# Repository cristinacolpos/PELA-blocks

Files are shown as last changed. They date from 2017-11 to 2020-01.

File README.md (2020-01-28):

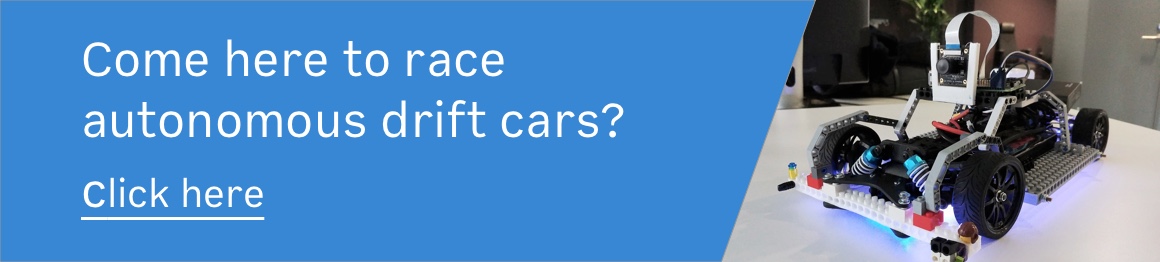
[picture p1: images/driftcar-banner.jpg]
PELA Drift Car (https://driftcar.pelablocks.org)


The fastest way to get support on designing and 3D printing your custom part is on [Discord PELA Blocks](https://discord.gg/Yy2srz)

# PELA Blocks

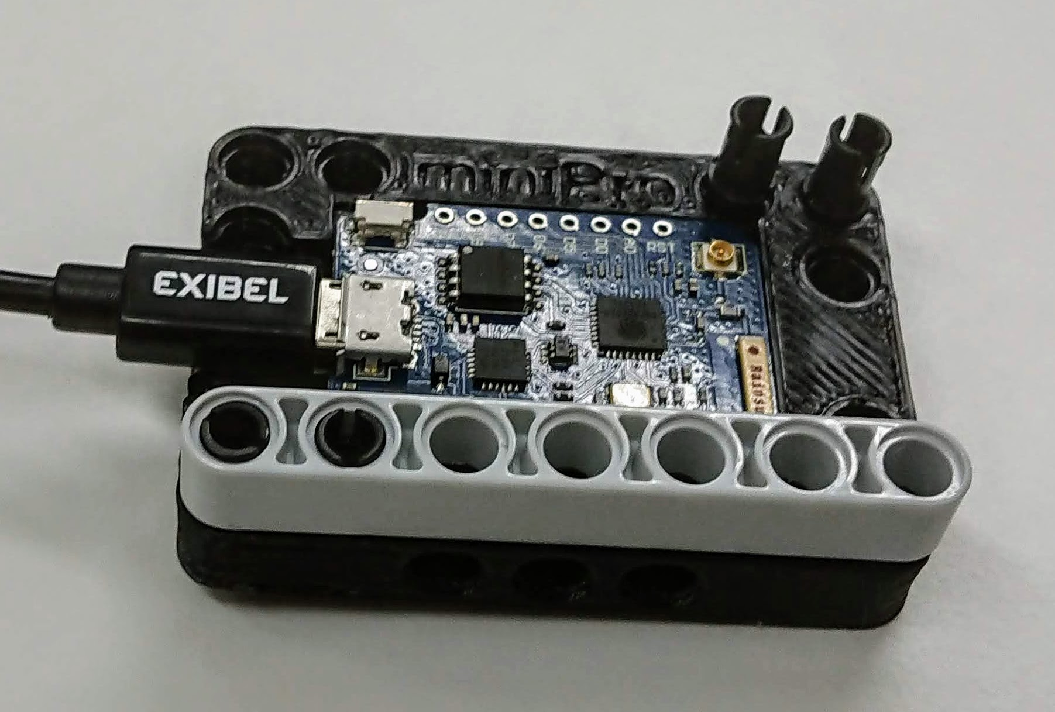
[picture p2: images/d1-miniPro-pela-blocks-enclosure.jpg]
ESP8266 d1 miniPro PELA Blocks enclosure


We measured the length, width and thickness of this board. Moving sliders in the customizer graphical interface of the  `PELA Technic Mount` created this functional prototype enclosure with nicely calibrated snap fit connectors. Now we can rapidly iterate our models in the field. 5 minutes plus 30 minutes for printing. This model is saved as a drop down preset of the `PELA Technic Mount` model.

Now you can design models without coding and snap them together!

## LEGO-compatible Parametric 3D Printed Blocks

PELA blocks are designed for easy 3D printing, strength, and rapid customization using free software. One time calibration gives perfect snap-together objects in exotic materials and geometries to help you explore your ideas and build with exotic materials and any motors and electronics you like. Example enclosures with many options for custom sensors, actuators, computers and IoT devices are included, or create your own.

These designs are not by the LEGO corporation. LEGO-compatible blocks are available from multiple manufacturers. Associated basic block patents expired long ago. Press-fit blocks existed before LEGO and we continue that tradition of adapt, evolve and improve as we provide these open source designs for 3D printing.

The name PELA comes from the Finnish "pelataan" meaning "let's play". This [blog post](https://medium.com/@futurice/rapid-hardware-prototyping-turbocharge-your-process-with-pela-blocks-58d0fcff63c5) on how we use these to build a self-driving 1:10 drift car is a good example of rapid prototyping "play".

## Download

**The STL files shown are not calibrated for your printer.** To get a good snap fit with your 3D printer and different material, you need to fine tune the size of knobs, sockets and technic holes. Some starting values are 

1. **[DOWNLOAD](https://github.com/LEGO-compatible-gadgets/PELA-blocks/archive/master.zip)** the latest designs, or `git clone git@github.com:LEGO-Prototypes/PELA-blocks.git --recurse-submodules`, then `git lfs install` in each git module
1. **[Calibrate](#calibrate)** the PELA Block models for your material and printer

See [Advanced Setup](ADVANCED-SETUP.md) for additional tricks.

See the [Slicer Recommendations](SLICER.md) for information about different printing materials we have tested.

## Calibrate

**TL;DR** *: To get a nice snap fit for your printer, slicer settings and material, print a calibration beam and test fit commercial bricks to the top knobs, bottom sockets and side technic holes. Update the best `top_tweak` and `bottom_tweak` into [`material.scad`](material.scad). Now open any model in OpenSCAD, press `F6` to generate the model then `F7` to export an STL.*

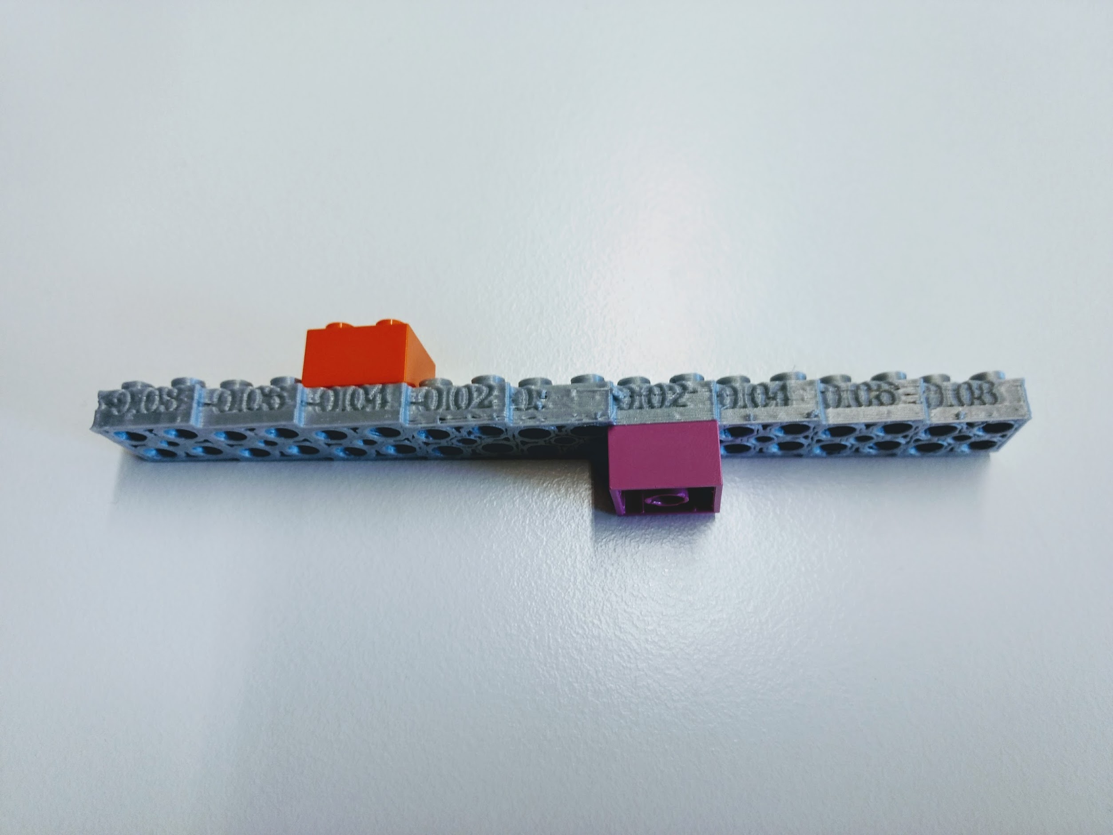
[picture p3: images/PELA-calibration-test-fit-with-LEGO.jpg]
PELA Example fit of a calibration block


There are several possible calibration beams. Most users will want the one linked below unless they are printing with flexible filament.

Test fit the top, bottom and sides to get something which is tight but not too tight. Then update your settings in  [`material.scad`](https://github.com/PELA-Prototypes/parametric-PELA/blob/master/material.scad) then one time calibration is complete.

## OpenSCAD Settings

The software needed is also free and open source, [OpenSCAD](https://www.openscad.org/). After install, `Edit | Preferences | Features | Customizer | Enable`. Also for large models and a fast machine, `Edit | Preferences | Advanced | Turn off rendering at _1000000_` and disable `OpenGL 1.0` compatability. 

You can also configure slicing and printing directly from OpenSCAD. See their website for details.

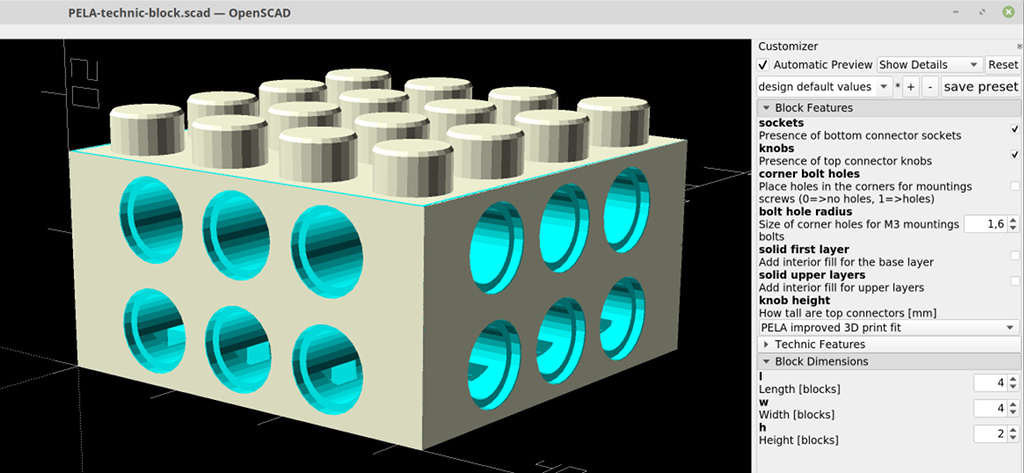
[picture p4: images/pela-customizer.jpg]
OpenSCAD Customizer with PELA Technic Block


___

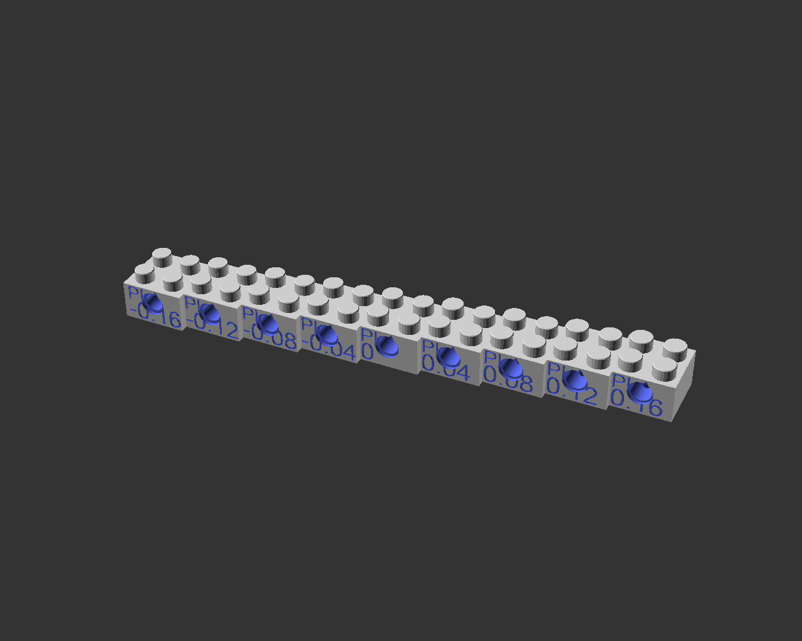
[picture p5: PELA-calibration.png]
PELA Calibration Beam, Normal Filament


[PELA Calibration Beam, Normal Filament](https://github.com/LEGO-compatible-gadgets/PELA-blocks/blob/master/PELA-calibration.stl) PELA Calibration Beam for standard filament (non-flexible).

### Calibration Instructions

Your printer, slicer settings, and plastic effect the precise fit. To correct for this, we adjust the models slightly for your printing process. Calibration is a one time process for each material. It is as simple as fitting two blocks together and editing a text file, [`material.scad`](material.scad) to indicate which test block fits best.

Before you print the calibration beam, be sure to set the `flexible_material` and `large_nozzle` settings in [`material.scad`](https://github.com/PELA-Prototypes/parametric-PELA/blob/master/material.scad).

After you print the clibration beam, you update three settings to get a tight fit: `top_tweak`, `bottom_tweak` and `axle_hole_tweak`. These can be read from the side of the calibration beam.

1. Print the Calibration Beam and test fit the top knobs and bottom sockets against commercial LEGO. Put the `top_tweak` (on the side, near the top) and `bottom_tweak` (on the side, near the bottom) values that you can read from the side of the beam into `material.scad`.
1. Use OpenSCAD to generate a new 2x2x1 `PELA Block` in OpenSCAD using these new settings, press `F6` to render, and `Export` as `.STL`.
1. Confirm a good fit with both commercial blocks and other PELA Blocks.
1. If you find you also need to adjust the technic connector hole size, print the Calibration Block Set. `axle_hole_tweak` numbers change along with `top_tweak` numbers.
1. Repeat this process as needed when you change material, nozzle size or and slicer settings which affect geometry.

## Advanced Calibration

An alternative set of individual calibration blocks are available, and if you have an unusual material there are other numbers you can tune such as various part thicknesses. See [Advanced Calibration](ADVANCED-CALIBRATION)

## PELA-compatible Part Designs

Edit `material.scad` and `style.scad` to adapt these models before printing them. **The example models below are not yet calibrated for your slicer and printer. Calibrate and then make the tuned model from the .scad file.**

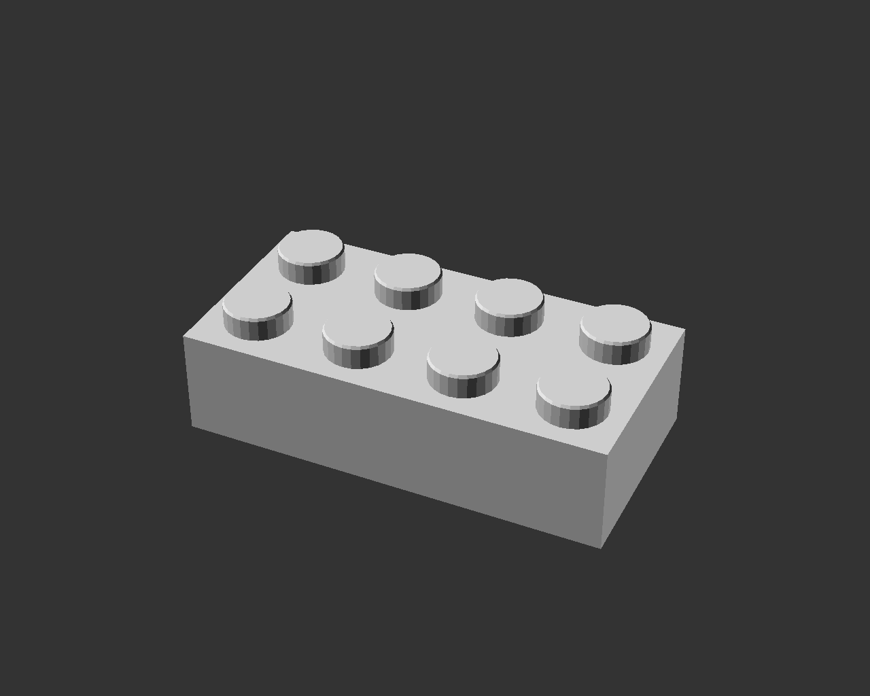
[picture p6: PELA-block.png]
PELA Block


[PELA Block](https://github.com/LEGO-compatible-gadgets/PELA-blocks/blob/master/PELA-block.stl)

___

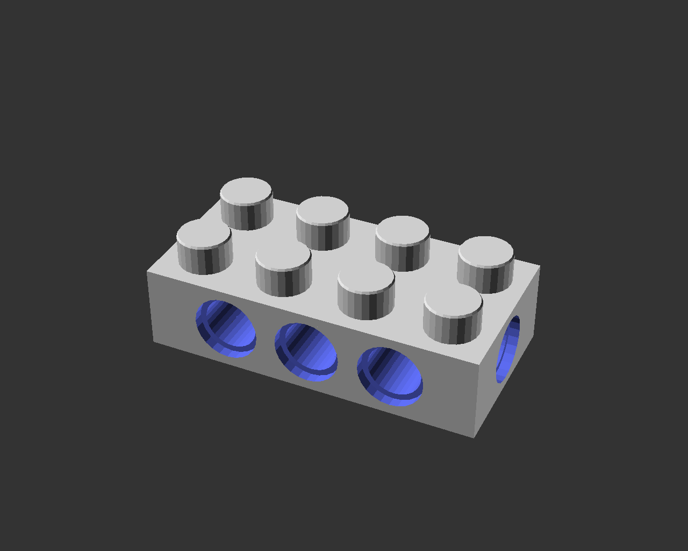
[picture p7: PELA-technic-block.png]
PELA Technic Block


[PELA Technic Block](https://github.com/LEGO-compatible-gadgets/PELA-blocks/blob/master/PELA-technic-block.stl) A blending of traditional and technic features which extends the basic block. All other models are extensions and variants of this.

___

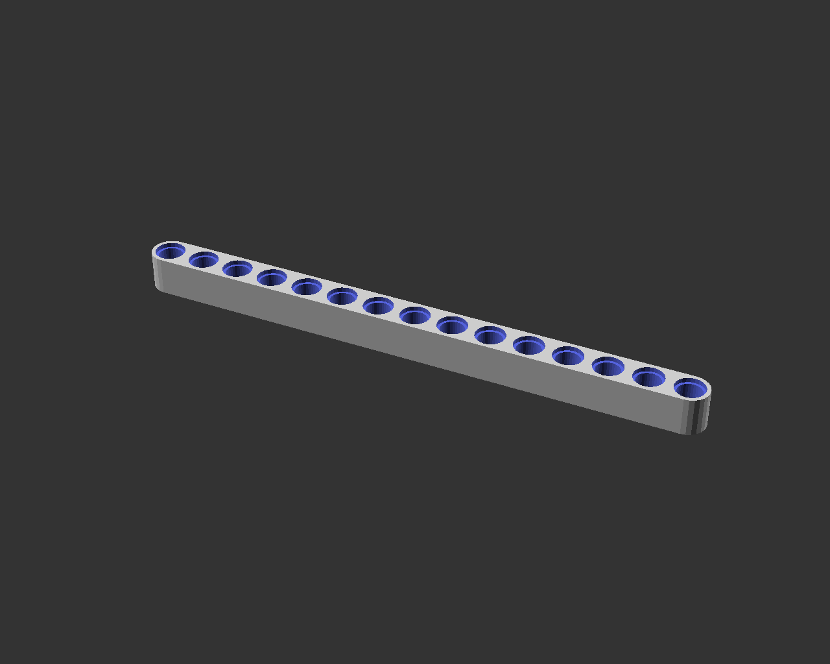
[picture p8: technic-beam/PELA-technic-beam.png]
PELA Technic Beam


[PELA Technic Beam](https://github.com/LEGO-compatible-gadgets/PELA-blocks/blob/master/technic-beam/PELA-technic-beam.stl) A minimalist technic beam.

___

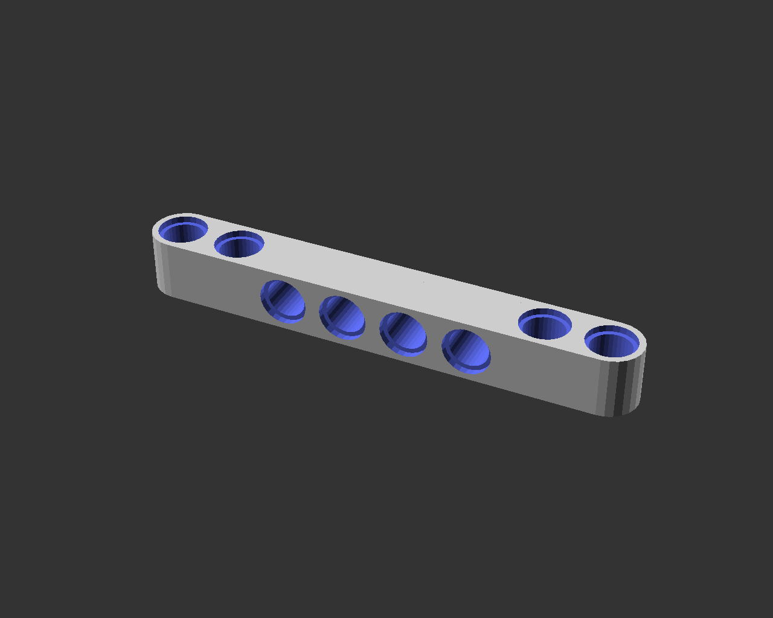
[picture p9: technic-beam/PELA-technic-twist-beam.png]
PELA Technic Twist Beam


[PELA Technic Twist Beam](https://github.com/LEGO-compatible-gadgets/PELA-blocks/blob/master/technic-beam/PELA-technic-twist-beam.stl) A technic beam with a center section of holes rotated 90 degrees.

___

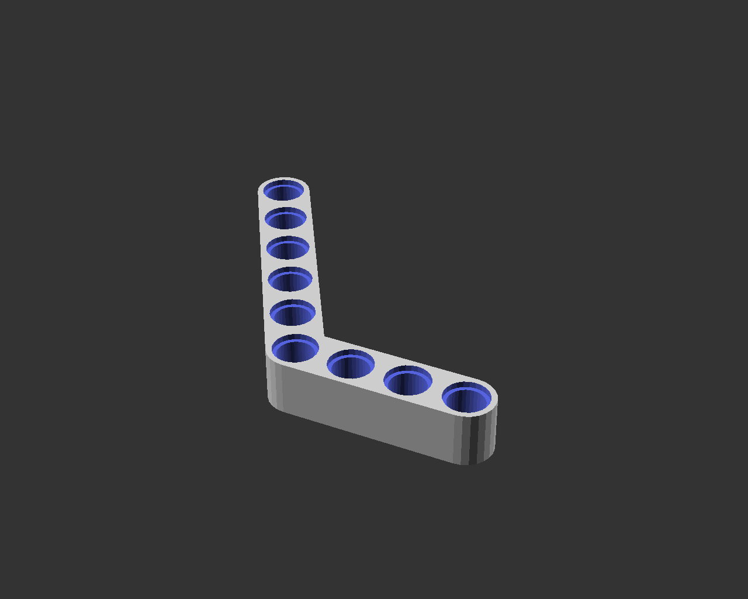
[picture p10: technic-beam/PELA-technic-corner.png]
PELA Technic Corner


[PELA Technic Corner](https://github.com/LEGO-compatible-gadgets/PELA-blocks/blob/master/technic-beam/PELA-technic-corner.stl) Two beams joined at an angle co-axial to the technic holes.

___

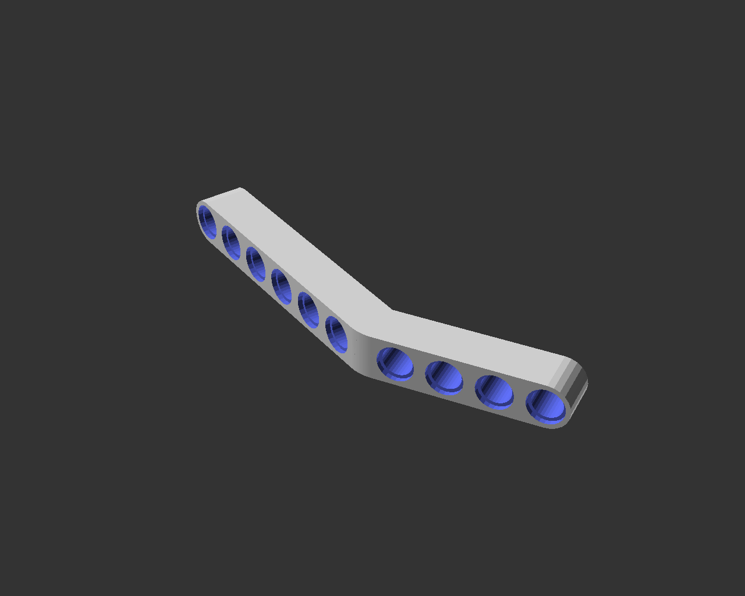
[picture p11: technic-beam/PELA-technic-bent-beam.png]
PELA Technic Bent Beam


[PELA Technic Bent Beam](https://github.com/LEGO-compatible-gadgets/PELA-blocks/blob/master/technic-beam/PELA-technic-bent-beam.stl) Two beams joined at an angle normal to the technic holes.

___

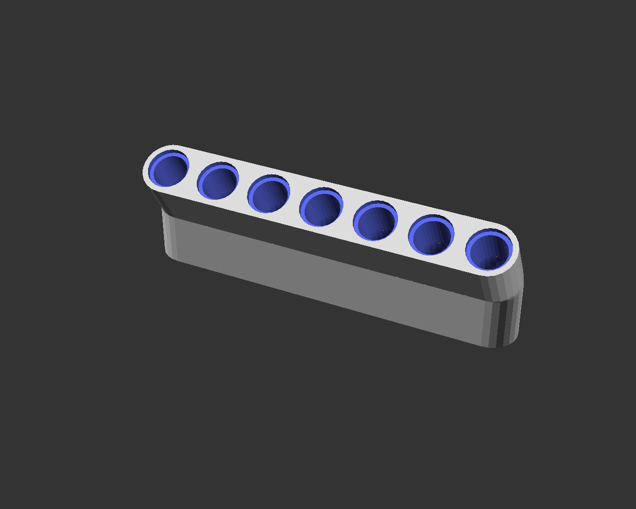
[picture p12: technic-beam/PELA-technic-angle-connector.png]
PELA Technic Angle Connector


[PELA Technic Angle Connector](https://github.com/LEGO-compatible-gadgets/PELA-blocks/blob/master/technic-beam/PELA-technic-angle-connector.stl) Two beams joined lengthwise at an angle.

___

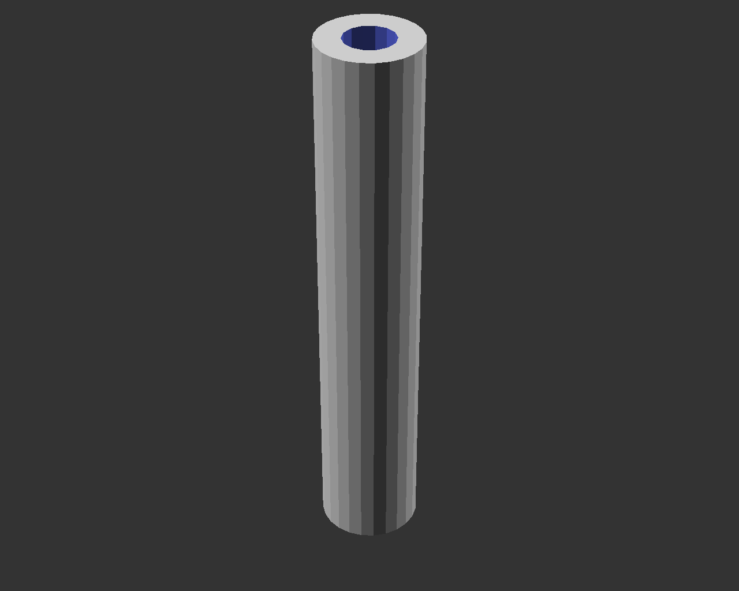
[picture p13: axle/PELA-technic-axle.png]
PELA Technic Axle


[PELA Technic Axle](https://github.com/LEGO-compatible-gadgets/PELA-blocks/blob/master/axle/PELA-technic-axle.stl) Rigid and flexible material shafts of adjustable length for attaching to other 3D printed designs such as wheels which you want to rotate freely.

___

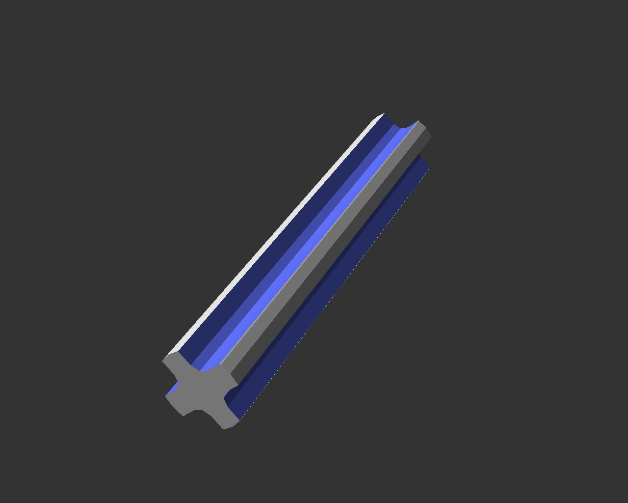
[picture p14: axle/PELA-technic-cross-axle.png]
PELA Technic Cross Axle


[PELA Technic Cross Axle](https://github.com/LEGO-compatible-gadgets/PELA-blocks/blob/master/axle/PELA-technic-cross-axle.stl) Rigid and flexible material torque drive shafts for adjustable length for attaching to other 3D printed designs.

___

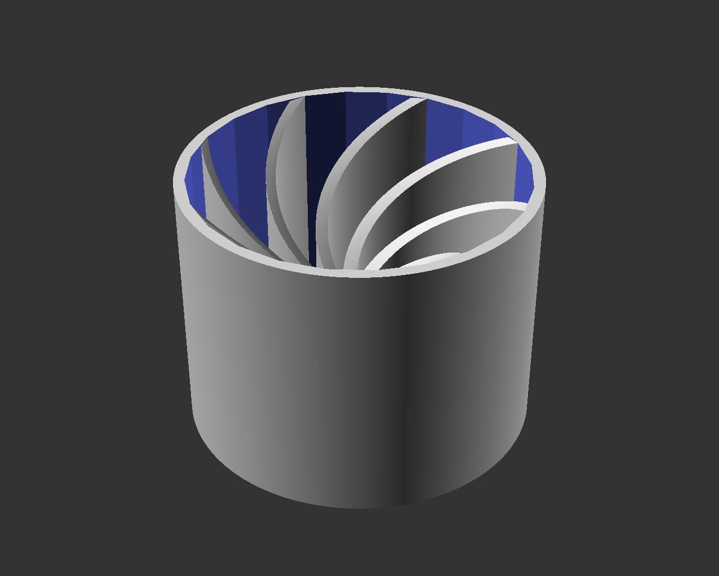
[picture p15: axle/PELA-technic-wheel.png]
PELA Technic Wheel


[PELA Technic Wheel](https://github.com/LEGO-compatible-gadgets/PELA-blocks/blob/master/axle/PELA-technic-wheel.stl) A spoked wheel that connects to a cross axle hub. Consider using flexible materials and tuning the wheel hardness as a simple shock absorber.

___

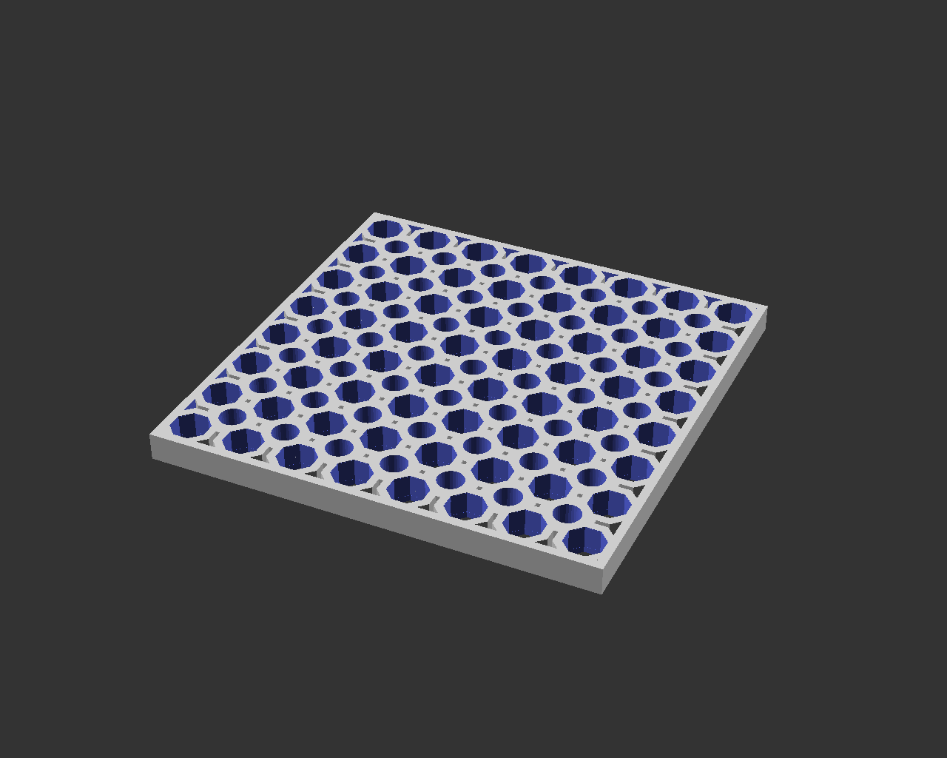
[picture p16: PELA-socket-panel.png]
PELA Socket Panel


[PELA Socket Panel](https://github.com/LEGO-compatible-gadgets/PELA-blocks/blob/master/PELA-socket-panel.stl) Insert knobs from both the top and bottom. Zoom in to see the subtle flexure ridges for enhanced "snap" fit.

___

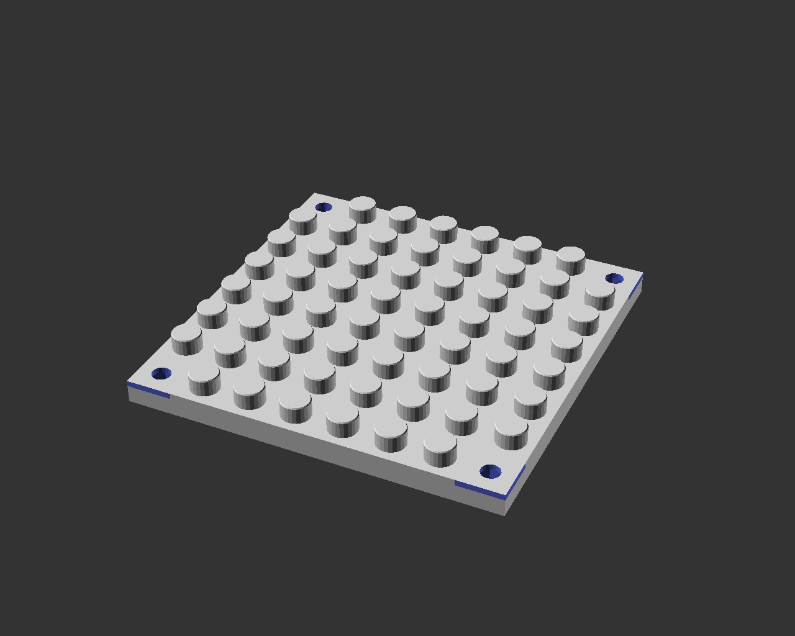
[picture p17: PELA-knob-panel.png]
PELA Knob Panel


[PELA Knob Panel](https://github.com/LEGO-compatible-gadgets/PELA-blocks/blob/master/PELA-knob-panel.stl) Optional corner holes for M3 bolts can be enabled

___

PELA Simplified Technic Peg

[PELA Simplified Technic Peg](https://github.com/LEGO-compatible-gadgets/PELA-blocks/blob/master/peg/PELA-simplified-technic-peg.stl) An easier-to-print version of a technic peg. This works best with a smaller nozzle and slightly flexible materials.

___

PELA Simplified Technic Peg for Flex Materials

[PELA Simplified Technic Peg for Flex Materials](https://github.com/LEGO-compatible-gadgets/PELA-blocks/blob/master/peg/PELA-simplified-technic-peg-flexmaterial.stl) An easier-to-print version of a technic peg for TPU95, TPU85/Ninjaflex and similar flexible materials.

___

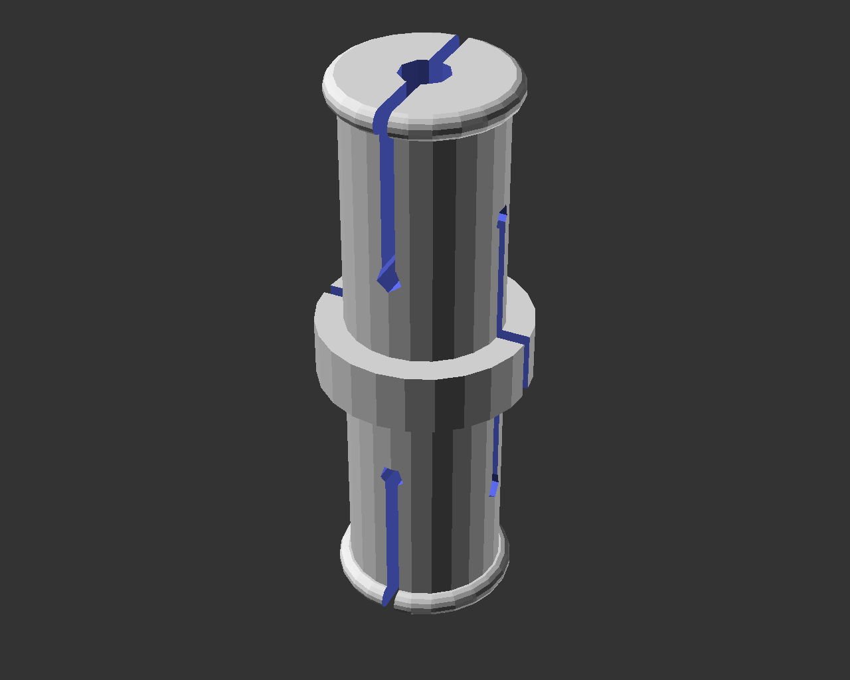
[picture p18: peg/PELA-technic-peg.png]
PELA Technic Peg


[PELA Technic Peg](https://github.com/LEGO-compatible-gadgets/PELA-blocks/blob/master/peg/PELA-technic-peg.stl) This is difficult to print with some material, but useful you run short and don't want to wait for mail order. It works best with slightly flexible materials.

___

PELA Technic Peg Array

[PELA Technic Peg Array](https://github.com/LEGO-compatible-gadgets/PELA-blocks/blob/master/peg/PELA-technic-peg-array.stl) A set of technic pegs.

___

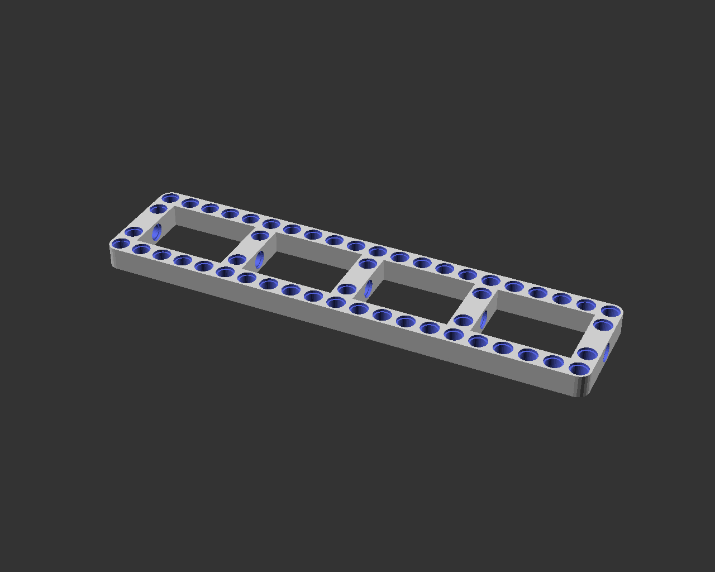
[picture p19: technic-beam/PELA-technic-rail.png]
PELA Technic Rail


[PELA Technic Rail](https://github.com/LEGO-compatible-gadgets/PELA-blocks/blob/master/technic-beam/PELA-technic-rail.stl) A variable length ladder-like mounting rail to bolt to a project board for clean, flexible layouts.

___

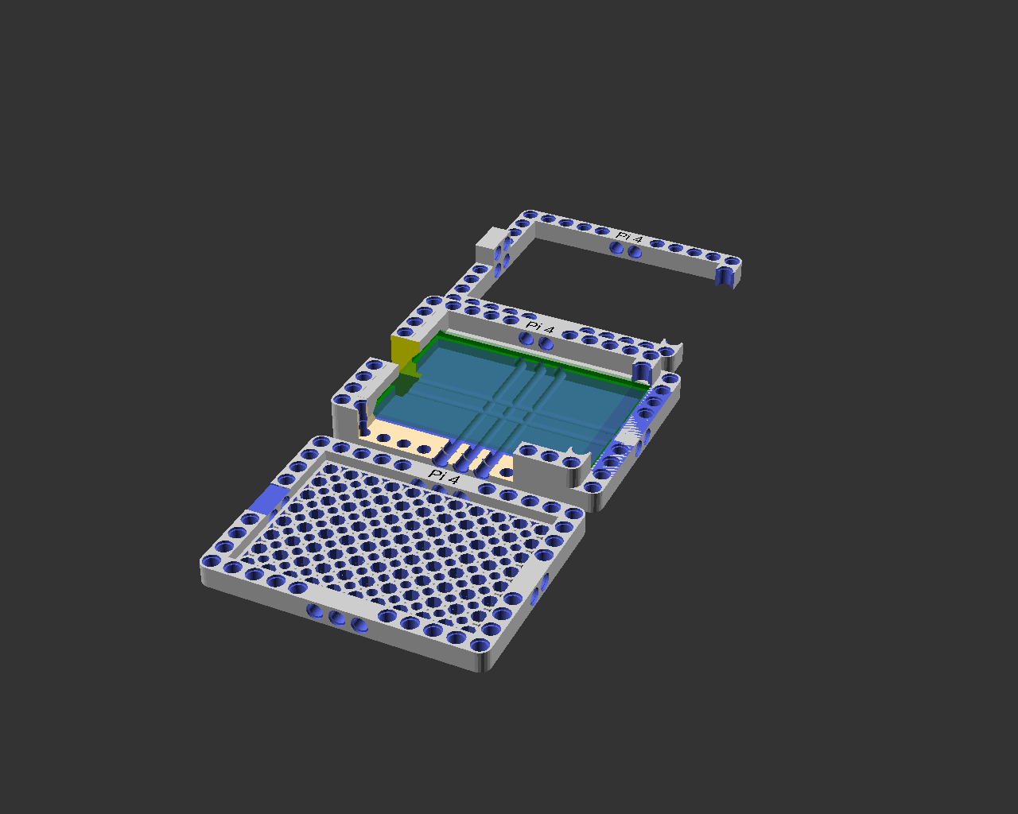
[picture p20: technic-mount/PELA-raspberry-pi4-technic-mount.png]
PELA Raspberry Pi 4 Technic Mount


[PELA Raspberry Pi 4 Technic Mount](https://github.com/LEGO-compatible-gadgets/PELA-blocks/blob/master/technic-mount/PELA-raspberry-pi4-technic-mount.stl) A Raspberry Pi 2/3B+/4 enclosure.

___

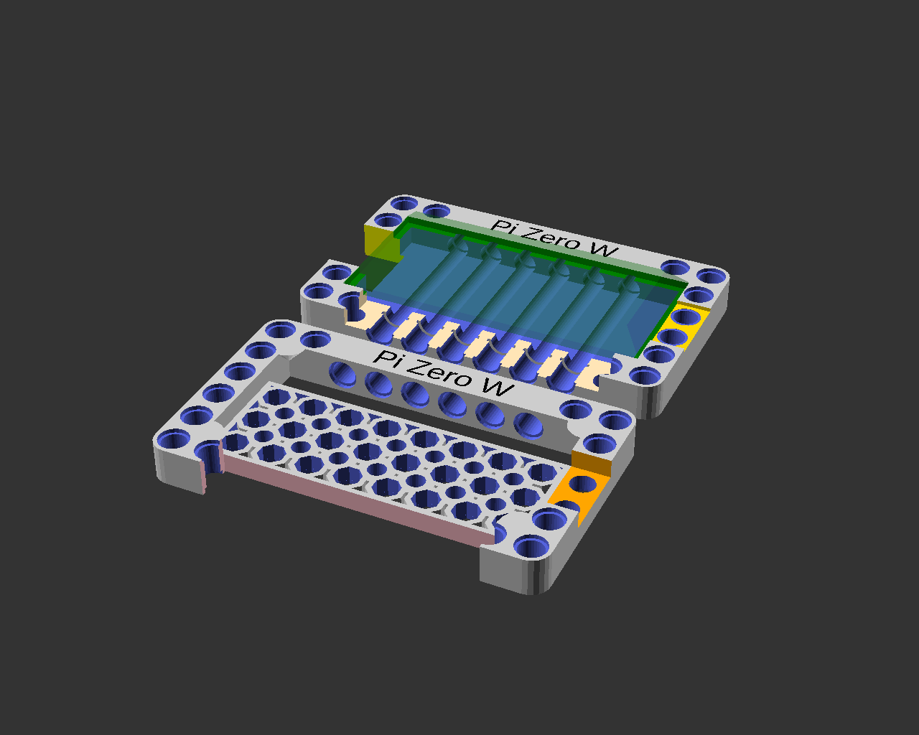
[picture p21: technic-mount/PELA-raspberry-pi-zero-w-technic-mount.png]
PELA Raspberry Pi Zero W Technic Mount


[PELA Raspberry Pi Zero W Technic Mount](https://github.com/LEGO-compatible-gadgets/PELA-blocks/blob/master/technic-mount/PELA-raspberry-pi-zero-w-technic-mount.stl) A Raspberry Pi Zero W holder.

___

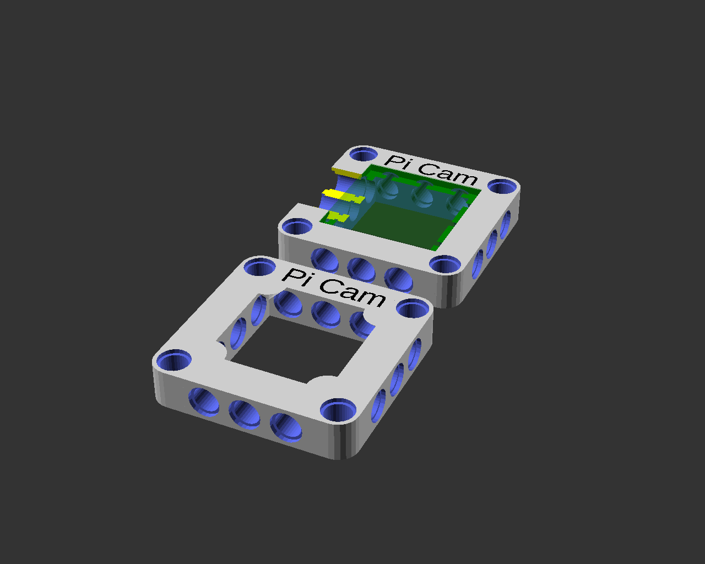
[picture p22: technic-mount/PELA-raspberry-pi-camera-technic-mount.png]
PELA Raspberry Pi Camera Technic Mount


[PELA Raspberry Pi Camera Technic Mount](https://github.com/LEGO-compatible-gadgets/PELA-blocks/blob/master/technic-mount/PELA-raspberry-pi-camera-technic-mount.stl) A Raspberry Pi camera holder.

___

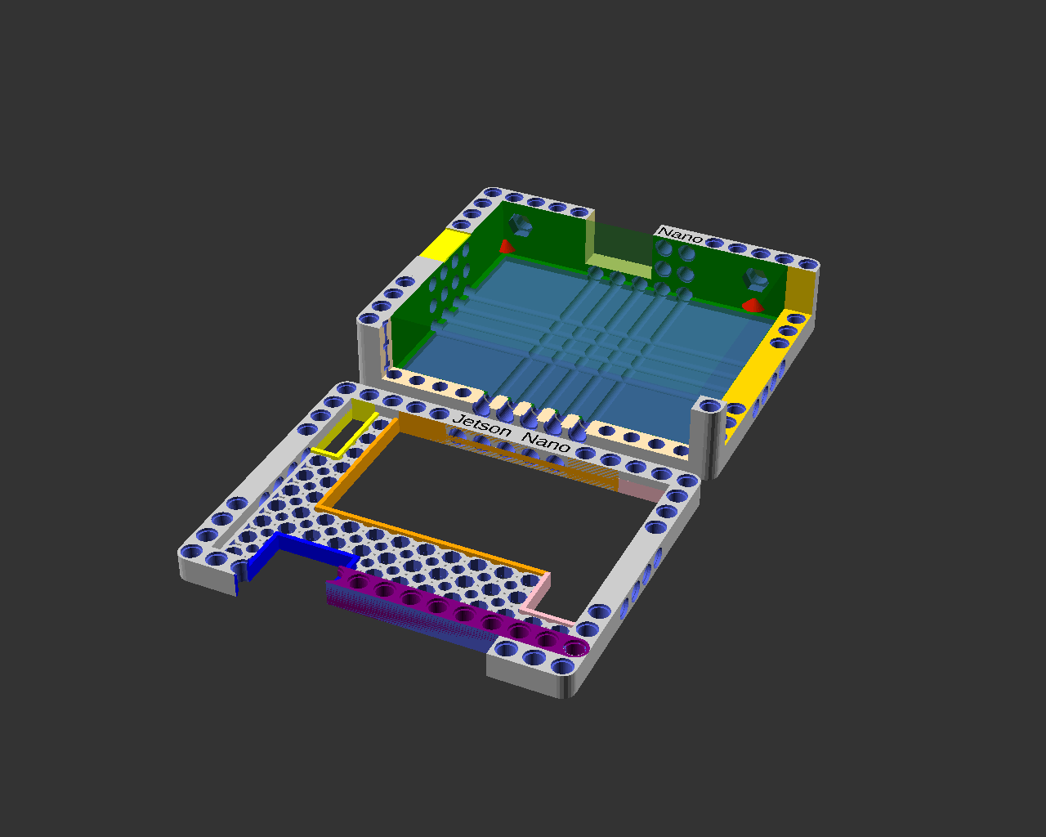
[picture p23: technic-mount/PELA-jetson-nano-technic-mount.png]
PELA Jetson Nano Technic Mount


[PELA Jetson Nano Technic Mount](https://github.com/LEGO-compatible-gadgets/PELA-blocks/blob/master/technic-mount/PELA-jetson-nano-technic-mount.stl) An NVIDEA Jetson Nano enclousure.

___

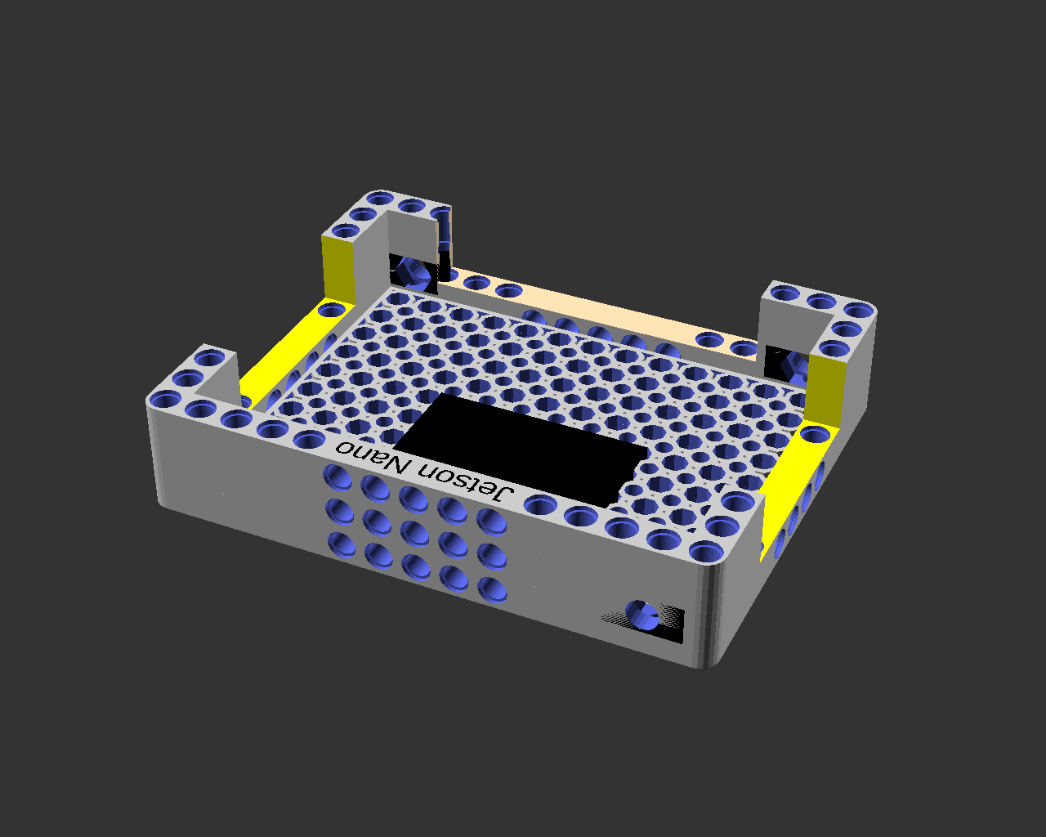
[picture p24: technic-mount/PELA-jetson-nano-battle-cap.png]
PELA Jetson Nano Battle Cap


[PELA Jetson Nano Battle Cap](https://github.com/LEGO-compatible-gadgets/PELA-blocks/blob/master/technic-mount/PELA-jetson-nano-battle-cap.stl) An NVIDEA Jetson Nano intrusion cover. This is useful to protect robots and self-driving cars from cooling fan impact damage which could break the PCB.

___

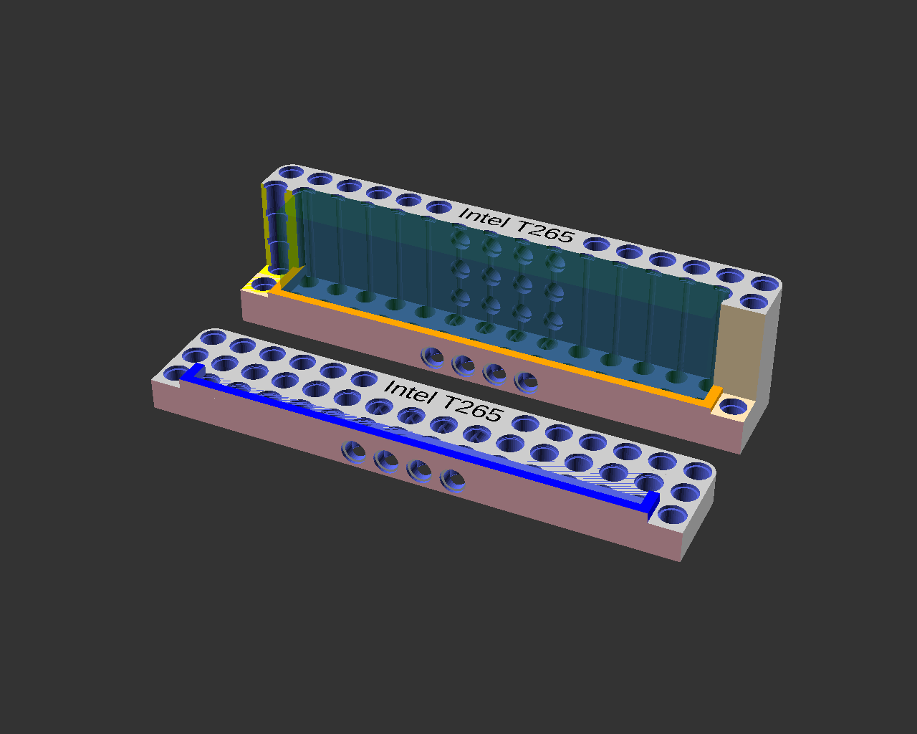
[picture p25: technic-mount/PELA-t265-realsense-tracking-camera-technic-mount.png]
PELA Intel T265 Realsense Tracking Camera Technic Mount


[PELA Intel T265 Realsense Tracking Camera Technic Mount](https://github.com/LEGO-compatible-gadgets/PELA-blocks/blob/master/technic-mount/PELA-t265-realsense-tracking-camera-technic-mount.stl) An enclosure for an [Intel T265](https://www.intelrealsense.com/tracking-camera-t265/) AI SLAM camera.

___

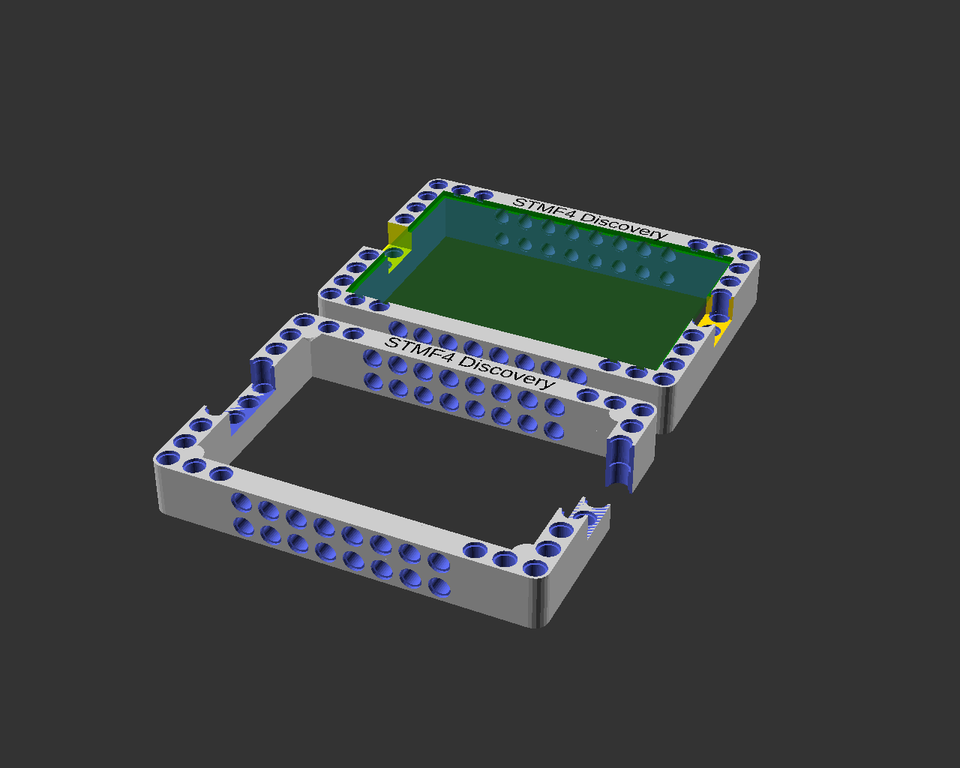
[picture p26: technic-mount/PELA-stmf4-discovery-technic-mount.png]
PELA STMF4 Discovery Technic Mount


[PELA STMF4 Discovery Technic Mount](https://github.com/LEGO-compatible-gadgets/PELA-blocks/blob/master/technic-mount/PELA-stmf4-discovery-technic-mount.stl) Enclosure for the [STMF4 Discovery](https://www.st.com/en/evaluation-tools/stm32f4discovery.html) board.

___

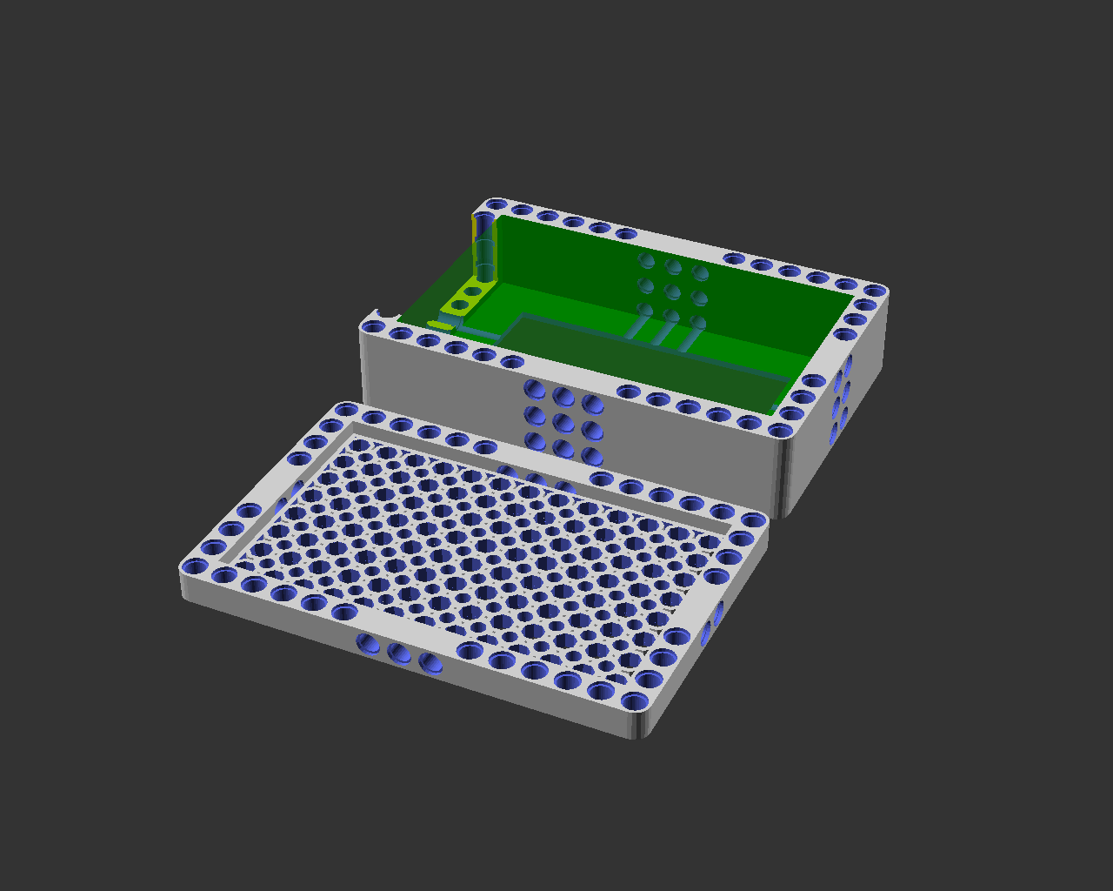
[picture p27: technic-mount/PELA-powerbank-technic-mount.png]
PELA Powerbank Technic Mount


[PELA Powerbank Technic Mount](https://github.com/LEGO-compatible-gadgets/PELA-blocks/blob/master/technic-mount/PELA-powerbank-technic-mount.stl) A container for a Clas Ohlson 38-3456 USB battery.

___

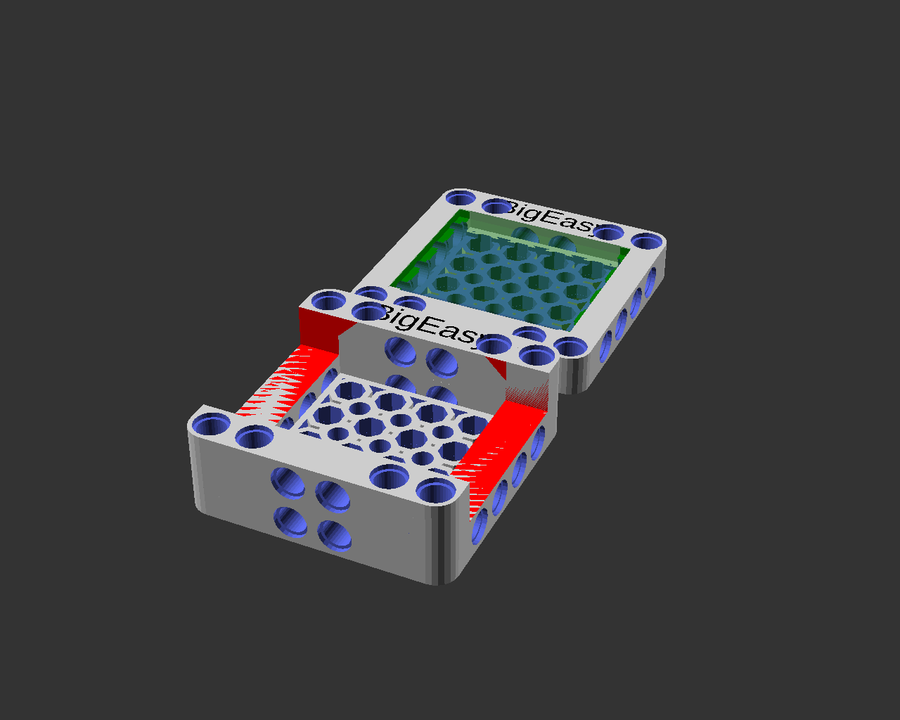
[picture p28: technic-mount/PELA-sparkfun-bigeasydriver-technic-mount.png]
PELA Sparkfun BigEasyDriver Technic Mount


[PELA Sparkfun BigEasyDriver Technic Mount](https://github.com/LEGO-compatible-gadgets/PELA-blocks/blob/master/technic-mount/PELA-sparkfun-bigeasydriver-technic-mount.stl) A pulsed infra-red motion sensor holder.

___

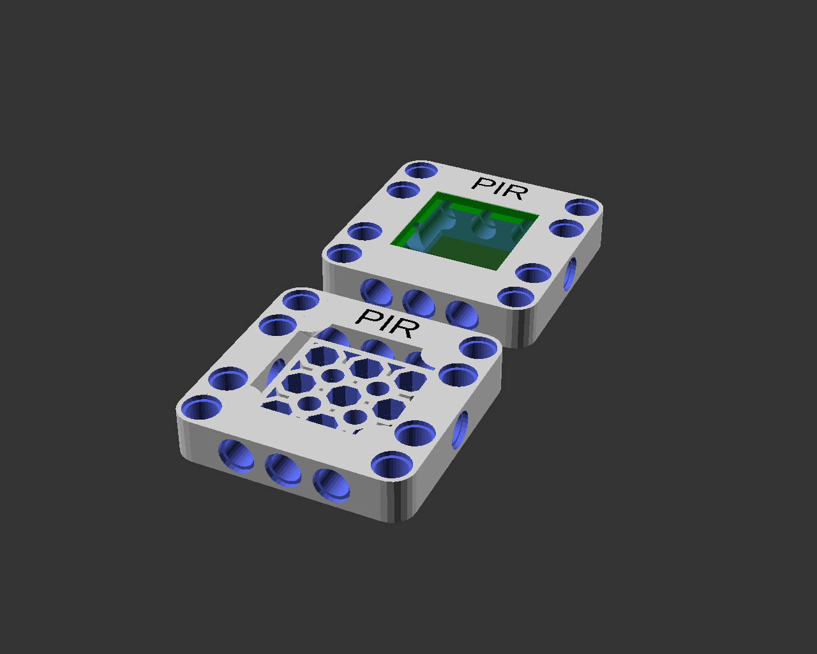
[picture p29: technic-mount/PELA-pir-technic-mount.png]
PELA Technic PIR Motion Sensor Mount


[PELA PIR Motion Sensor Technic Mount](https://github.com/LEGO-compatible-gadgets/PELA-blocks/blob/master/technic-mount/PELA-pir-technic-mount.stl) A pulsed infra-red motion sensor holder.

___

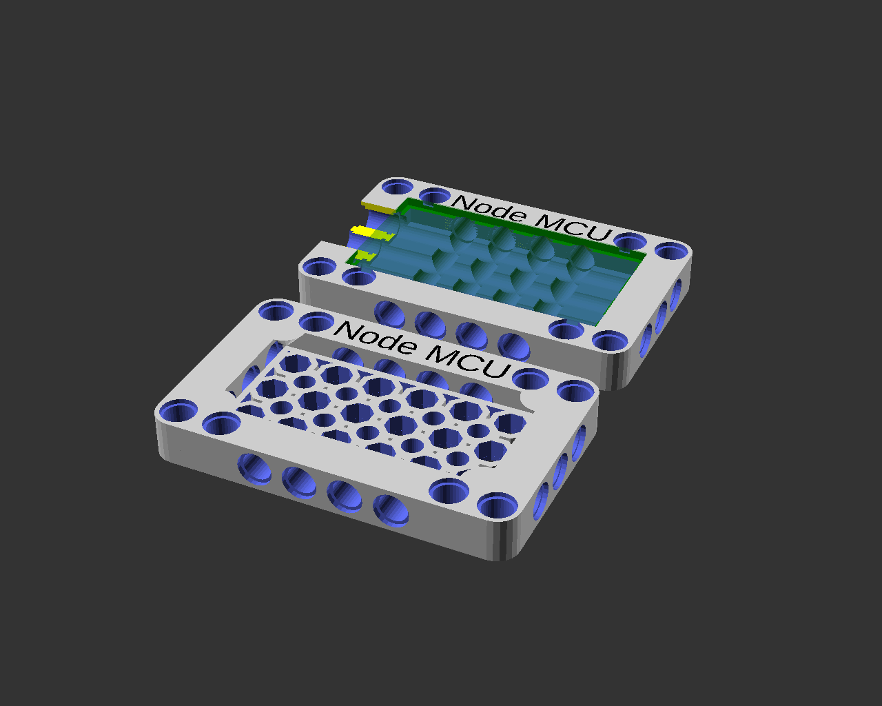
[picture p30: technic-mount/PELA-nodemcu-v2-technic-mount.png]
PELA Technic NodeMCU v2 Mount


[PELA Technic NodeMCU v2 Mount](https://github.com/LEGO-compatible-gadgets/PELA-blocks/blob/master/technic-mount/PELA-nodemcu-v2-technic-mount.stl) A technic mount for NodeMCU v2.

___

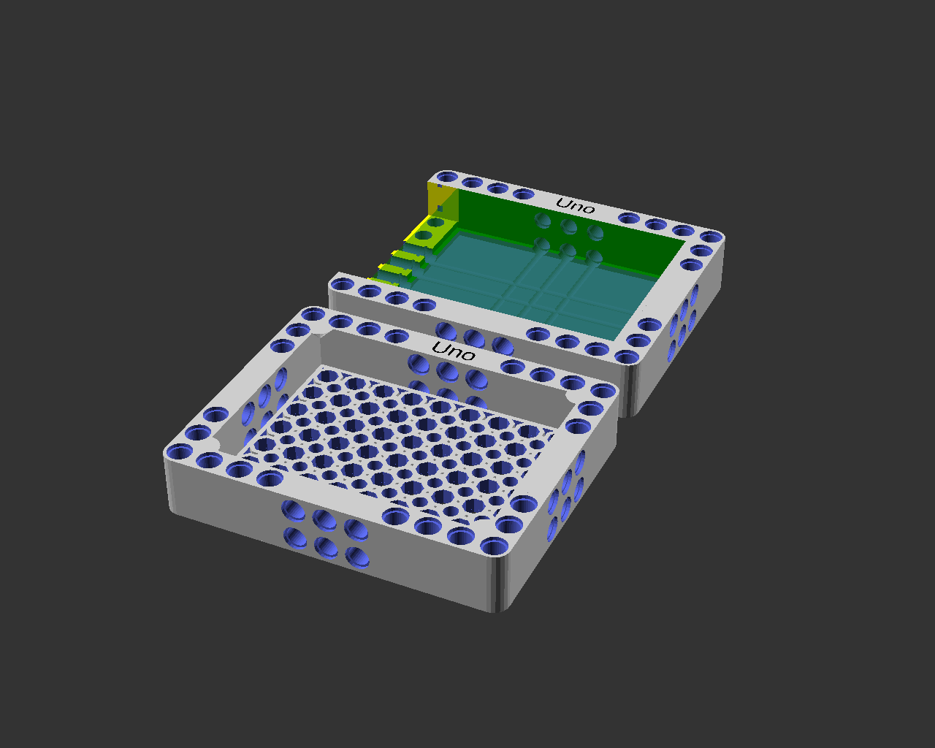
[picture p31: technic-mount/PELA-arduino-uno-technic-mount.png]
PELA Arduino Uno Technic Mount


[PELA Arduino Uno Technic Mount](https://github.com/LEGO-compatible-gadgets/PELA-blocks/blob/master/technic-mount/PELA-arduino-uno-technic-mount.stl) For holding an Arduino Uno microcontroller board within a PELA block

___

PELA Technic Seeed Respeaker Core v2 Mount

[PELA Technic Seeed Respeaker Core v2 Mount](https://github.com/LEGO-compatible-gadgets/PELA-blocks/blob/master/technic-mount/PELA-respeaker-core-v2-mount.stl) A technic mount for the Respeaker Core v2 microphone array.

___

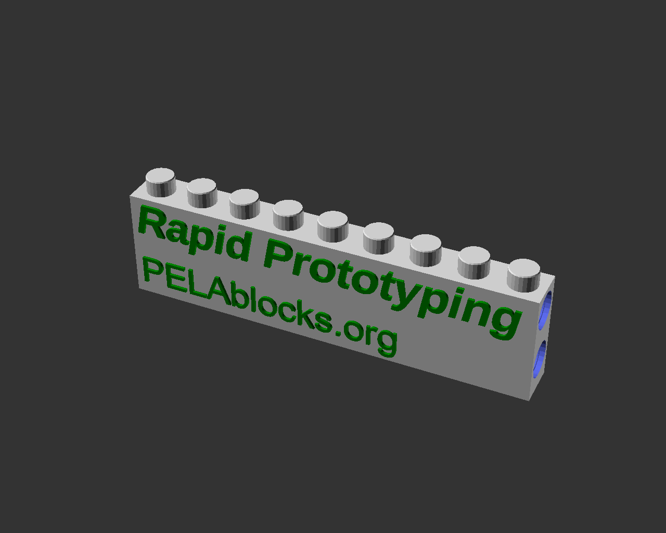
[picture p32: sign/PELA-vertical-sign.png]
PELA Vertical Sign


[PELA Vertical Sign](https://github.com/LEGO-compatible-gadgets/PELA-blocks/blob/master/sign/PELA-vertical-sign.stl) Change the text to label your designs. Options include front and back text with either etched for raised text.

___

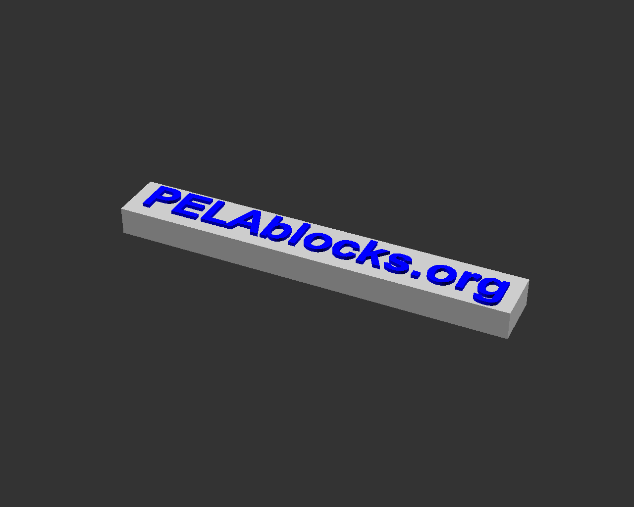
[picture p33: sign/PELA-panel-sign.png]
PELA Panel Sign


[PELA Panel Sign](https://github.com/LEGO-compatible-gadgets/PELA-blocks/blob/master/sign/PELA-panel-sign.stl) Change the text to label your design either etched for raised text.

___

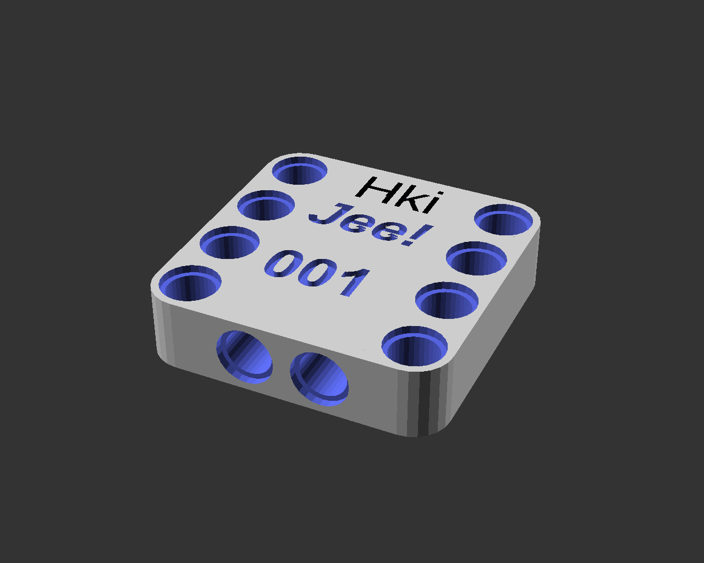
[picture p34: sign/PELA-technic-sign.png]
PELA Technic Sign


[PELA Technic Sign](https://github.com/LEGO-compatible-gadgets/PELA-blocks/blob/master/sign/PELA-technic-sign.stl) Change the text to label your design.

___

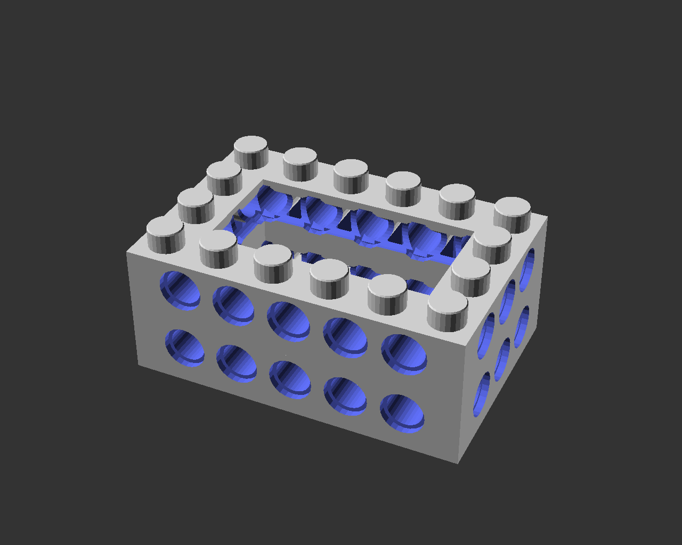
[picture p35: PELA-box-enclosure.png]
PELA Box Enclosure


[PELA Box Enclosure](https://github.com/LEGO-compatible-gadgets/PELA-blocks/blob/master/PELA-box-enclosure.stl) A generic enclosure for mounting boards inside protective side walls.

___

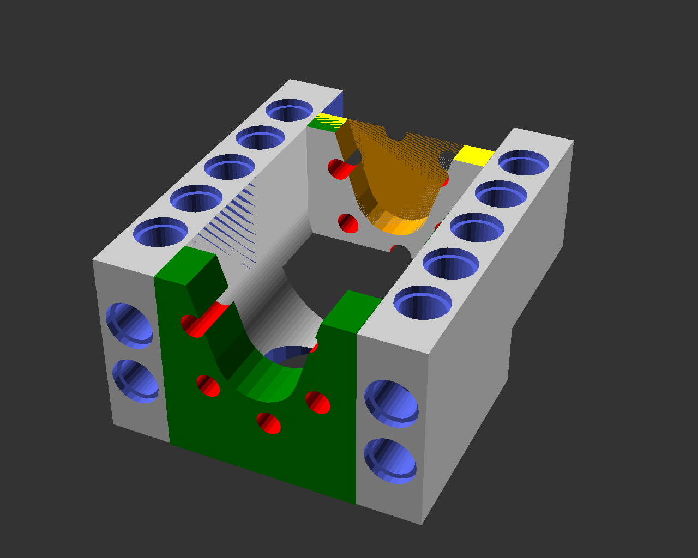
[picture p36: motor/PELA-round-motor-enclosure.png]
PELA Round Motor Enclosure


[PELA Round Motor Enclosure](https://github.com/LEGO-compatible-gadgets/PELA-blocks/blob/master/motor/PELA-round-motor-enclosure.stl) Add a round round motor holder for 1:10 electric cars

___

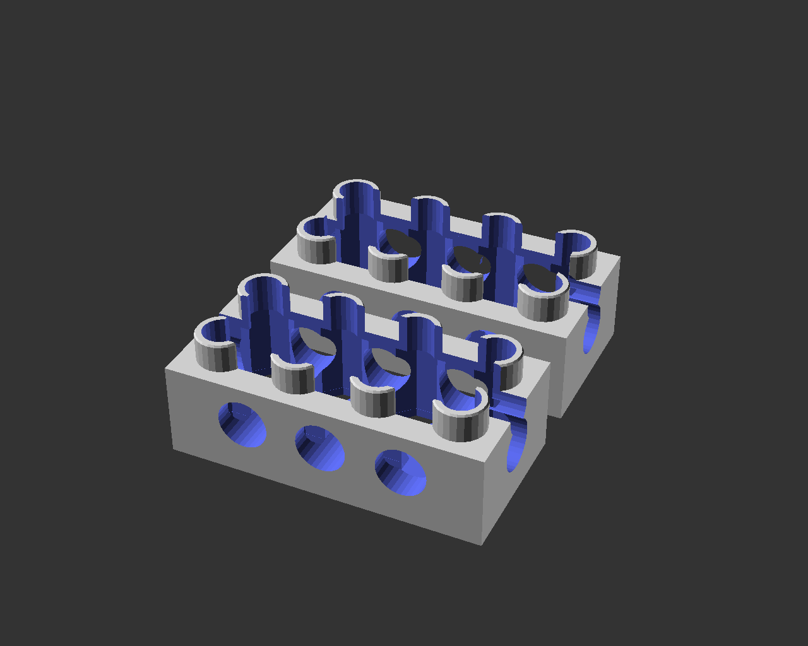
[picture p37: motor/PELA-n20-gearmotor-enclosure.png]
PELA N20 Gearmotor Enclosure


[PELA N20 Gearmotor Enclosure](https://github.com/LEGO-compatible-gadgets/PELA-blocks/blob/master/motor/PELA-n20-gearmotor-enclosure.stl) Add a commonly available small gear motor to your design. Adjust the model parameters to fit other motor sizes.

___

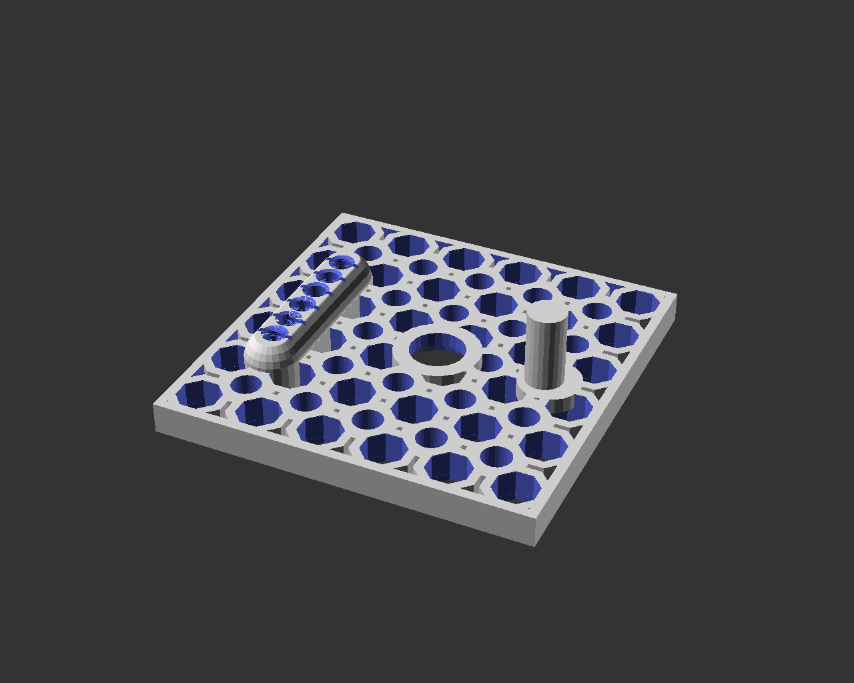
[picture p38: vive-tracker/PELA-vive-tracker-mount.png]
PELA HTC Vive Tracker Mount


[PELA HTC Vive Tracker Mount](https://github.com/LEGO-compatible-gadgets/PELA-blocks/blob/master/vive-tracker/PELA-vive-tracker-mount.stl) [HTC Vive Tracker](https://www.vive.com/) attachment to your designs becomes easy to remove.

___

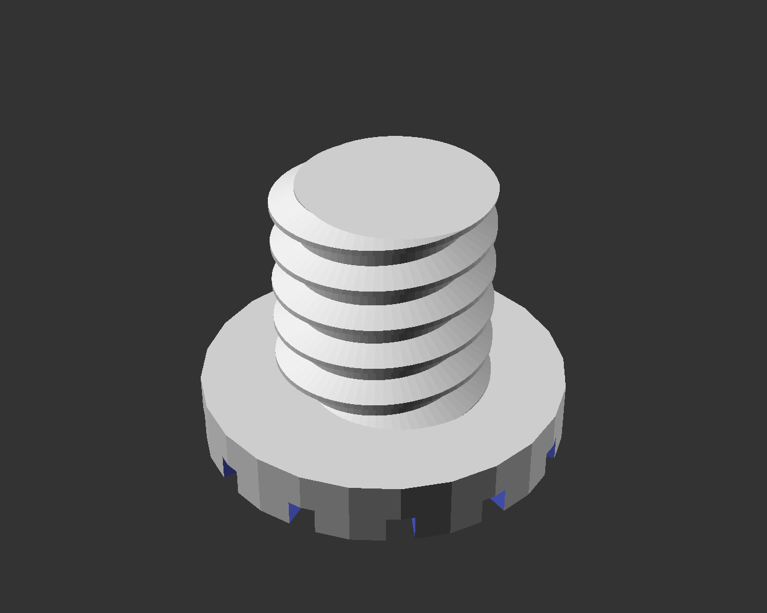
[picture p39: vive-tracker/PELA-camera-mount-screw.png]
PELA Camera Mount Screw


[PELA Camera Mount Screw](https://github.com/LEGO-compatible-gadgets/PELA-blocks/blob/master/vive-tracker/PELA-camera-mount-screw.stl) You can use this quarter inch standard camera mount screw for flush mounting the HTC Vive to the Vive Tracker Mount. The printed version works better than you might expect.

___

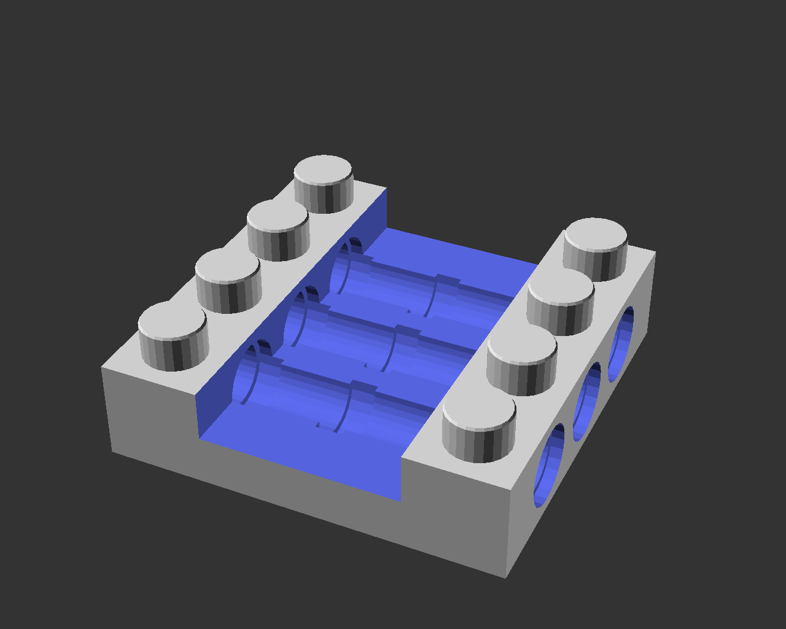
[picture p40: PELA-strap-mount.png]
PELA Strap Mount


[PELA Strap Mount](https://github.com/LEGO-compatible-gadgets/PELA-blocks/blob/master/PELA-strap-mount.stl) For attaching using strap or similar straps through the bottom slot. For example use this with velcro straps to mount Vive trackers on your shoes..

___

PELA PCA9685 16 Channel Servo Board Technic Mount

[PELA PCA9685 16 Channel Servo Board Technic Mount](https://github.com/LEGO-compatible-gadgets/PELA-blocks/blob/master/technic-mount/PELA-pca9685-servo-board-technic-mount.stl) For holding a servo board within a PELA block with connectors exposed at one end. We use these with 1:10 RC drift cars and Rasperry Pi for a [PELA drift car](https://driftcar.pelablocks.org/) in the [Markku Invitational](https://markku.ai/) contest based on [Donkeycar](https://www.donkeycar.com/).

## FFF Printing Tips
§
* Use a 0.4mm or smaller nozzle if possible to avoid decimation of some socket details
* If slicing with Simplify 3D with 0.5mm or larger nozzle, you may want to set Simplify 3D to `Advanced | External Thing Wall Type | Allow single extrusion walls`
* Be aware that slicers may in some cases not be able to correct OpenSCAD STL export errors. These errors should be visible in layer preview as for example extra excursions back to origin. If this happens, open and clean the STL files first with for example Microsoft 3D Builder, Meshmixer or MeshLab. MeshLab command line examples can be found in `build.ps1`.
* Best results are achieved with durable materials that are not too stiff (PET, co-polymers like NGEN, semi-flexible and "engineering" materials instead of PLA and  carbon filled).
* Best results are achieved with smaller nozzle diameters. Adjust slicer settings for precision over speed. Layer height is not particularly important on most models.
* Think carefully before using very slippery materials such as Nylon.
* "standard" and "fast" print setting layer lines are helpful for extra connector grip provided the resulting print geometry is sufficiently accurate.
* A print "brim" the appears inside the model may negatively affect the bottom connector fit
* Leaving the blocks on a heated bed may negatively affect the bottom connector fit

## Resin Printing Tips

* If more than 2 layer tall PELA with a relatively solid interior not allowing drainage below the knobs, check if you need to expand the airhole to allow resin to drain from the flexure chamber inside each knob
* For translucent materials, setting knob_slice_count to 0 may make the interior structure look more like a standard PELA at the cost of a slight reduction of knob sidewall flex

## License



These designs are by PELA project contributors, not by the LEGO corporation. They are compatible with LEGO and similar blocks available from multiple manufacturers and online projects. The associated patents have expired. These designs are not identical to LEGO; they have been specially modified for easy 3D printing and offered in the spirit of open source collaborative innovation.

If what you want is available as injection molded plastic, buy it for the higher quality and durability. These model are helpful when you want something customized, a special color, an unusual material, and for replacement parts when you just can't wait.

Futurice (https://futurice.com)

These open source designs are brought to you by [Futurice](https://futurice.com) and contributions from the community. Come work with the best.

## Projects Using PELA Blocks

PELA has been used to create a self-driving car: 3D Printed LEGO-compatible Parametric 1:10 Scale RC Drift Car Based On PELA Blocks (https://driftcar.pelablocks.org)

[![PELA Technic Rails]()](https://github.com/LEGO-compatible-gadgets/PELA-blocks/blob/master/technic-beam/PELA-technic-rail.stl) and enclosures are a great way to make bigger IOT projects without the duct tape: 
IOT Rail Mounting Solution Based On PELA Blocks

PELA is also used to create robot parts: 3D Printed LEGO-compatible Parametric Robot Hand (https://robothand.pelablocks.org)

The generated 3D models displayed here are hosted in a separate GitHub project to minimize the size of pulling changes in this repo: [PELA-blocks](https://github.com/LEGO-compatible-gadgets/PELA-blocks)

## Alternative 3D Block Designs

If you don't find what you need, consider adding it, contact us or check out the many other excellent design available.

[marian42's excellent online technic part generator](https://marian42.de/partdesigner/) can help you make custom connectors and fixture easily. 

[Yeggi search for LEGO](https://www.yeggi.com/q/lego/)

[Thingiverse Parametric LEGO Group](https://www.thingiverse.com/groups/parametric-lego) is an alternate source for these block designs. These designs don't work with the online customizer (speed and complexity, multiple files), so the best path is still to install the newest [OpenSCAD](https://www.openscad.org/) and **[download](https://github.com/LEGO-compatible-gadgets/PELA-blocks/archive/master.zip)** the models.

## Contact

New models, collaboration and pull requests are welcome. You have the tools- now create something cool and share with the world : https://github.com/LEGO-compatible-gadgets/PELA-blocks

paul.houghton@futurice.com ( **[Blog](https://medium.com/@paulhoughton)** - **[Twitter](https://twitter.com/mobile_rat)**)

If you like what you see, please tweet and let others know!

Twitter link (https://twitter.com/intent/tweet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)

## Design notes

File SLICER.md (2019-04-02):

# PELA Blocks
## Slicer Recommmendations

Our experience with different materials are recommended below. Unless otherwise noted, prints are on a Lulzbot Taz 6, 0.5mm extruder, using LulzBot Cura.

Most designs are adjusted to print upright with any layer height. There is very little infill with most designs so using 50% does not greatly affect print speed. Adjust settings to minimize "hop and hunt" during printing on the intricate inner geometry. Avoid "brim" and "support" options if possible as they require difficult post-processing. Most models are do not require supports, but some models offer a switch for minimal, pre-placed supports added to the model. Minimize bed heating if you find the bottom edge distorted by melting.

# Disable slicer print supports

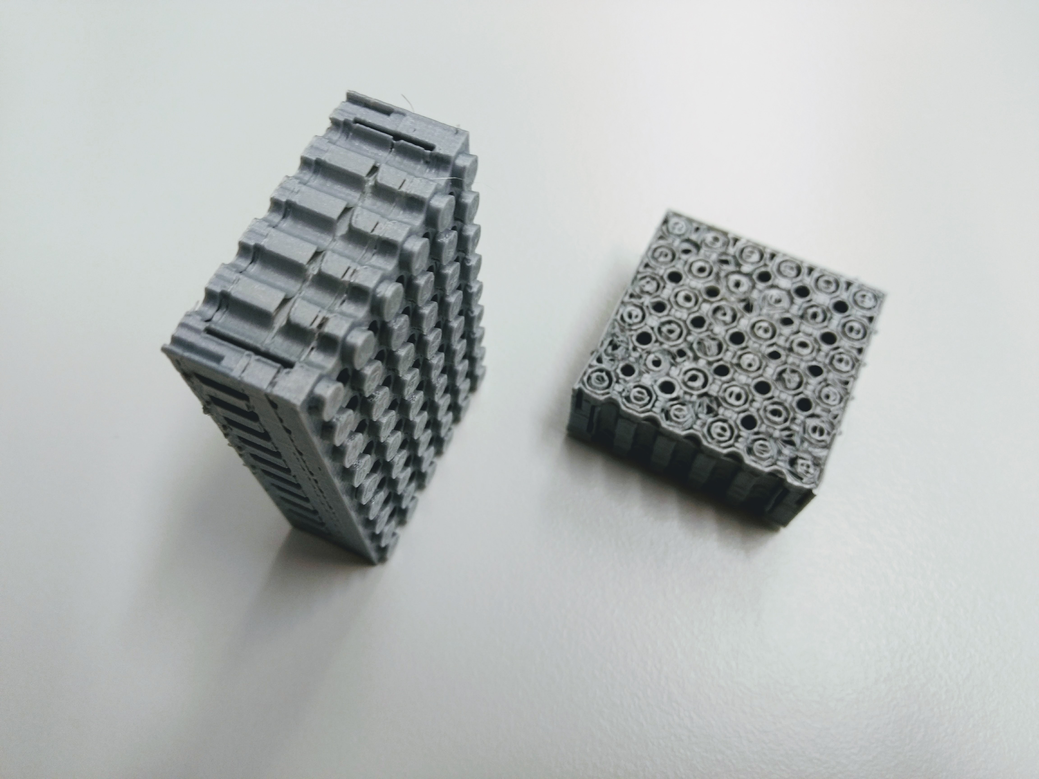
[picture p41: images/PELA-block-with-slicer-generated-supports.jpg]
PELA block with slicer-generated supports


In some models you can turn on `print_supports = true;` to enable pre-placed supports baked into the model. These may work better the slicer automatic supports to minimize post processing.

# PLA

Works surprisingly well if you use a premium PLA which has some flex to it. Some brands can be stiff and chip easily. That results in a more difficult part fit for knobs and sockets, but not so much problems with technic connector axle holes.

Avoid or minimize bed heating- it can "elephant foot" the lower socket connectors resulting in a poor fit.

# ABS

This is a good material if you are familiar with handling ABS shinkage. This is not much of an issue if your parts are not too large or too tall. LEGO is made from ABS because it has many nice properties if you know how to minimize lift and delamination due to thermal contraction in larger parts.

Not all brands of ABS are the same. Village Plastics ABS gives better results than some others.

# Innofil rPET

It works but is not ideal due to high stiffness and brittle failure. rPET is made from recycled plastic bottles. Like other transparent/translucent materials you can overextrude for more clarity. Just make sure you also print your calibration beam with the same overextrusion.

Other PETs which have more flex may be a good choice but have not been evaluated.

## Slicer Settings

`Layer Height: 0.25`     (for transparency- taller is fine and prints faster)

`Print Temp: 245C`

`Build Plate: 85C`

`Flow: 105%`

`Fan: 30%`

`Retraction: 8.5mm`

`Retraction Speed: 25mm/s`

`Speed: 80mm/s`

`Bottom Speed: 40mm/s`

`Support: None`   (see 'PEL-material.scad' where support can be added to some models)

`Adhesion: Skirt`

`Infill: 20%`   (minimal effect, most models this can be 50% without taking more time)

`Wall Line Count: 1`

`Fill Gaps Between Walls: Nowhere`

Optional Finish: Lightly sand the outer surface and spray with a clear polimer.

# Innofil Pro1

A nice engineering co-polimer with good gemetric stability and able to print fast and hold well to the print bed. It has good flexture- more than PET but still rigid.

## Slicer Settings

`Layer Height: 0.25`   (the manufacturer states lower layer heights are stronger and more aesthetic)

`Fan: 20%`   (lower speed is stronger layer adhesion, more speed gives cleaner geometry)

# Colorfabb NGEN

A strong, glossy material with a brittle failure mode. It works but is slightly tricky to get a good fit with classic knobs and sockets. As with PET/other co-copolymer filaments, unless you seek transparency then do not overextude. Consider adding more fan if layer adhesion is sufficent. Due to brittle failure knobs are particularly sensitive to breaking off from delamination in which case you may want to anneal parts in an oven or lower the fan for better layer adhesion.

## Slicer Settings

`Layer Height: 0.3`   (or smaller for aesthetics and when there is side text in the model)

`Print Temp: 255C`

`Initial Print Temp: 250C`

`Build Plate: 85C`

`Flow: 95%`

`Fan: 50%`

`Enable Coasting: true`

`Speed: 60mm/s`

`Wall Speed: 30mm/s`

`Support: None`

`Adhesion: Skirt`

`Infill: 20%`   (minimal effect, most models this can be 50% without taking more time)

`Wall Line Count: 1`

`Fill Gabs Between Walls: Nowhere`

# Colorfabb NGEN Flex

Works well on Taz6 Flexistruder with an 0.6mm nozzle. Basically the same settings as NGEN but without the drawbacks of being brittle which is very nice. Like NGEN it is a rather low friction glossy finish so calibration is still slightly sticky.

`Fan: 50%` or less for better inter-layer adhesion

# ColorFabb HT

Avoid. It is like NGEN but even more stiff, brittle failure and a slippery finish. It takes a long time to clean this sticky stuff from your printer.

# TPU85/NinjaTek NinjaFlex

Works well on a Taz6 Flexistruder with 0.6mm nozzle. Gluestick acts as a release agent that protects the PEI print surface from damage, or use tape or plain glass with gluestick.

## Slicer Settings

`Adhesion: Brim` Make sure the brim is only on the outside to avoid a difficult cleanup. Cura has an option for this. `Adhesion: Raft` also works but the bottom surface may be uneven. Minimize bed heating and use other adhesives during printing if needed to avoid "elephant foot" or "corner peel up" on the lower socket connectors.

`Infill: 20%`   (minimal effect, most models this can be 50% without taking more time)

`Wall Line Count: 1`

`Fill Gaps Between Walls: Nowhere`

`Keep Heating: No`

# Taulman Bridge Nylon

A very nice material for PELA blocks, but also very slippery. Use a bed of watery PVA white glue and take care not to permanently stick to a PEI or similar sheet. Use a lot of retraction to avoid string cleanup. Speed is your friend- print fast and retract fast and far, and enable "coast".

## Slicer Settings

`Layer Height: 0.3`

`Fill gaps between walls: Nowhere`       (Use Everywhere if the block is printed tilted or on the side)

`Keep Heating: No`      (Bed heater can be disabled after the print)

`Retraction Distance: 3mm`

`Retraction Speed: 20 mm/s`

`Print Speed: 100 mm/s`

`Number of Slow Layers: 1`

`Equalize Filament Flow: Yes`     (Move faster over thin walls)

`Print Cooling: 100%`

`Enable Coasting: Yes`    (Stop extrusion before the end of a segment to minimize oozing)

`Keep Heating: No`

# Biofila Silk

This is one of the most attractive filaments and biodegradable. It is between PLA and ABS is flexability and durability. Make sure you have good bed adhesion and adjust the settings for quick, long retraction to minimize stringing.

## Slicer Settings

`Layer Height: 0.25`

`Printing Temperature: 175C`

`Build Plate: 60C`

`Keep Heating: No`

`Infill: 50%`    (minimal impact on time)

`Fill gaps between walls: Nowhere`       (Use Everywhere if the block is printed tilted or on the side)

`Retraction Distance: 3mm`

`Retraction Speed: 20 mm/s`

`Print Speed: 70 mm/s`

`Number of Slow Layers: 1`

`Equalize Filament Flow: Yes`     (Move faster over thin walls)

`Print Cooling: 100%`

`Enable Coasting: Yes`    (Stop extrusion before the end of a segment to minimize oozing)

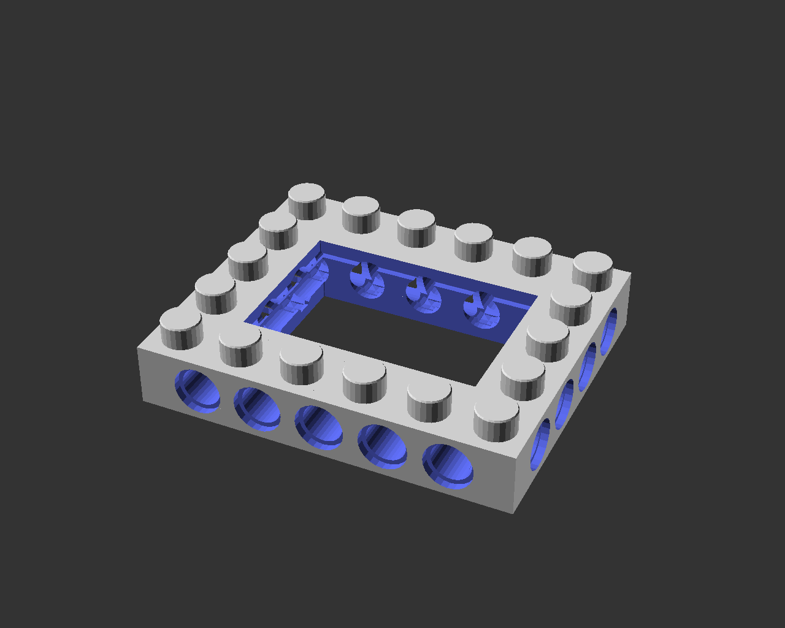
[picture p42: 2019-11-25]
PELA-knob-mount.png

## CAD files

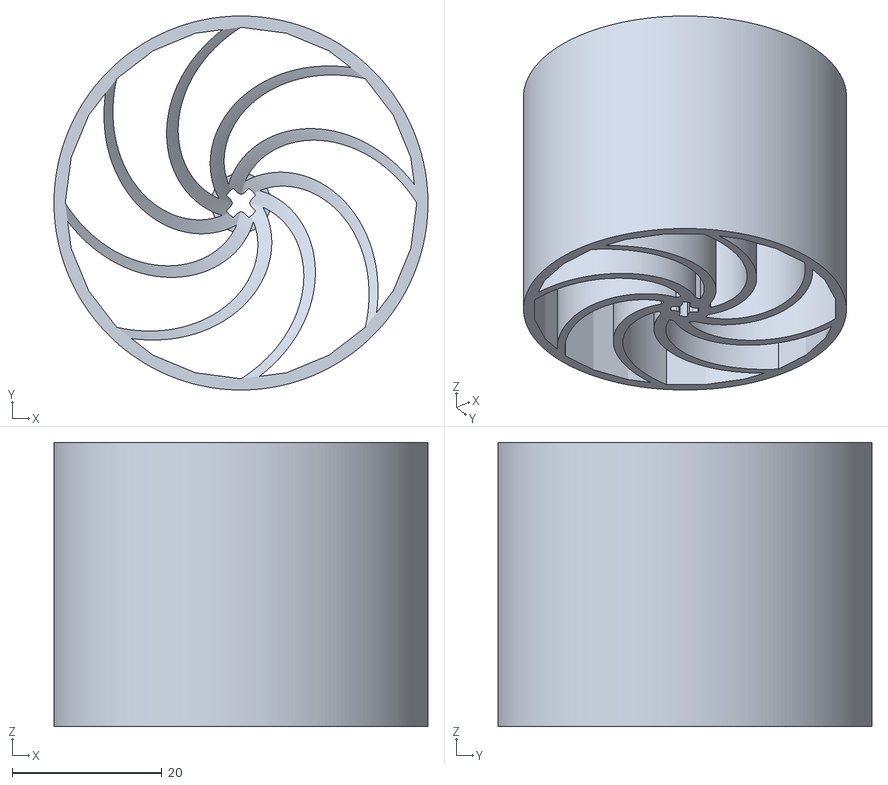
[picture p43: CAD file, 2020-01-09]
axle/PELA-technic-wheel.stl
50.0 x 50.0 x 38.0

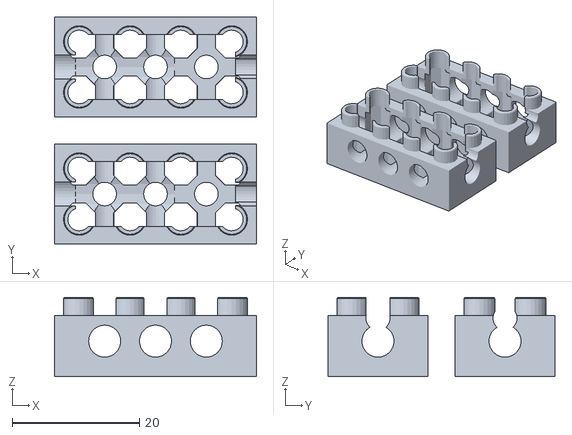
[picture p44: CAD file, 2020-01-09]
motor/PELA-n20-gearmotor-enclosure.stl
31.8 x 35.8 x 12.5

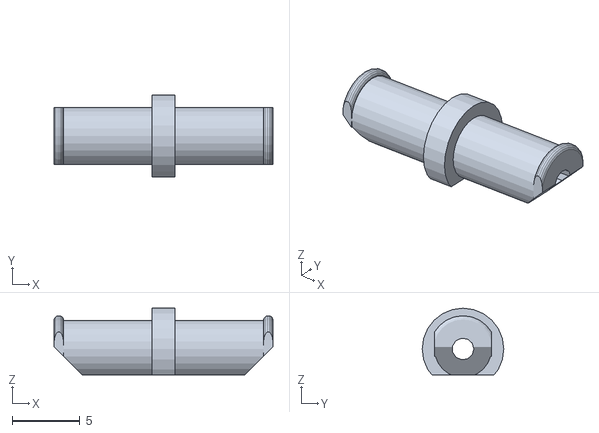
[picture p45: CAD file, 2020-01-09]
peg/PELA-simplified-technic-peg.stl
16.1 x 6.00 x 4.90

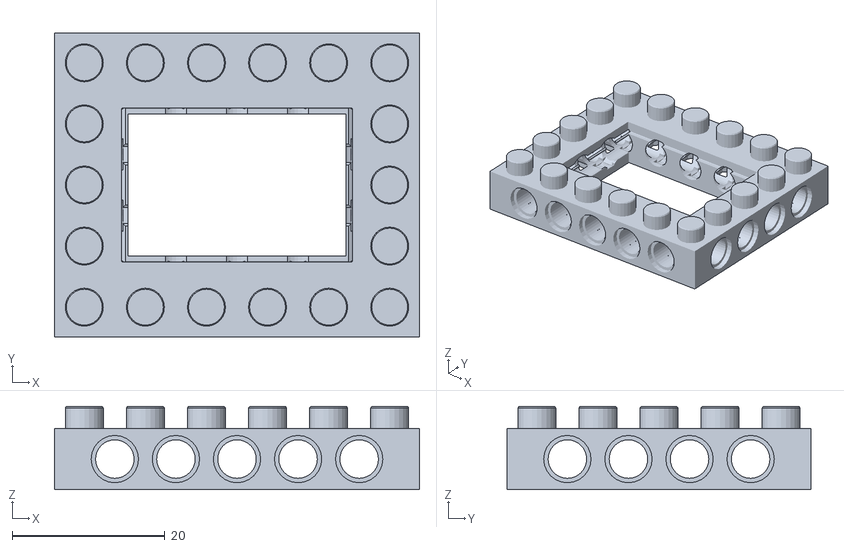
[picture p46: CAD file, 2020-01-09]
PELA-knob-mount.stl
47.8 x 39.8 x 10.9

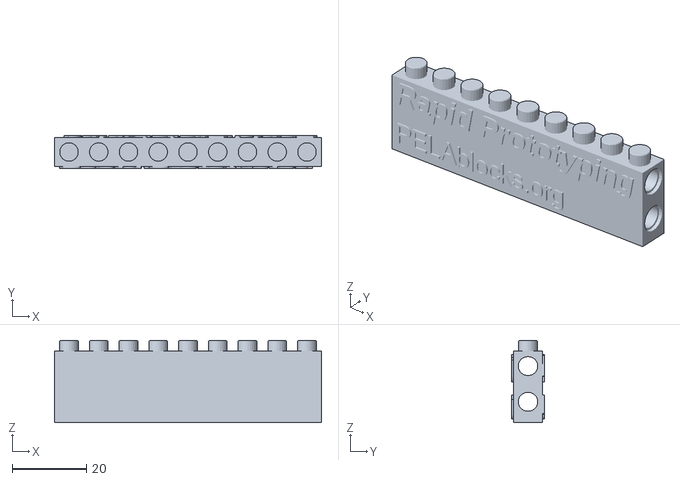
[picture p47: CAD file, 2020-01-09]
sign/PELA-vertical-sign.stl
71.8 x 8.80 x 22.1

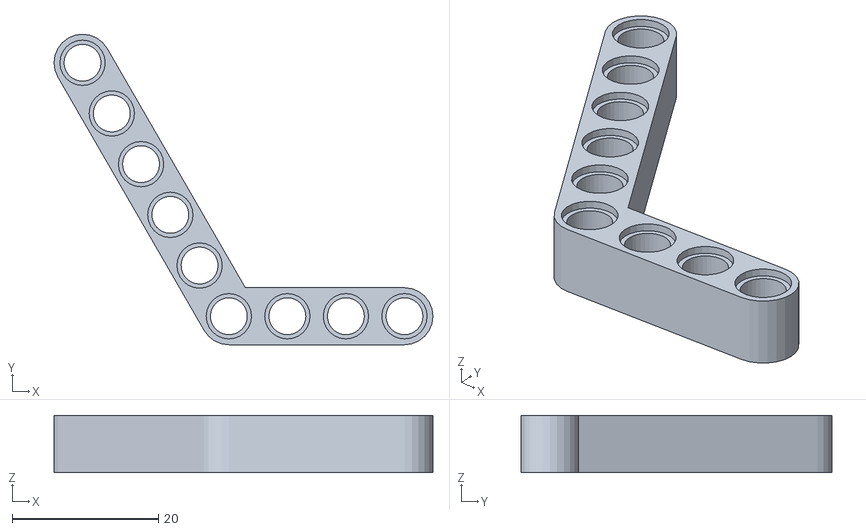
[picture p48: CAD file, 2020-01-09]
technic-beam/PELA-technic-corner.stl
51.8 x 42.4 x 7.80

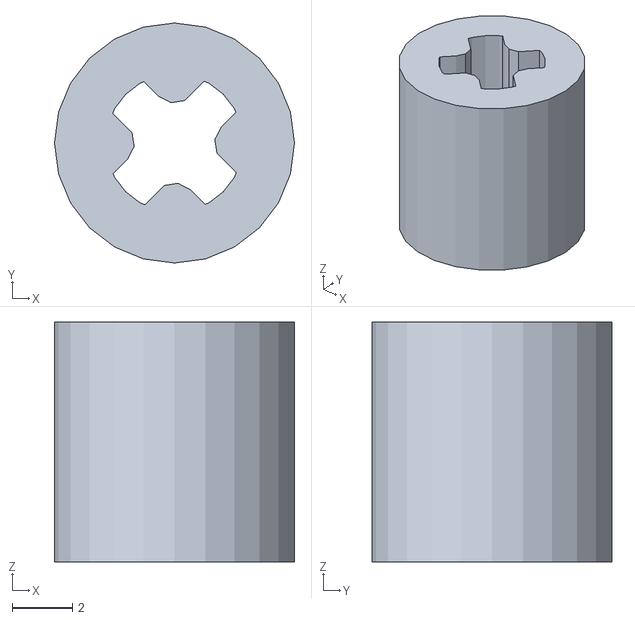
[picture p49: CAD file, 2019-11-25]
axle/PELA-technic-hub.stl
8.00 x 8.00 x 7.99

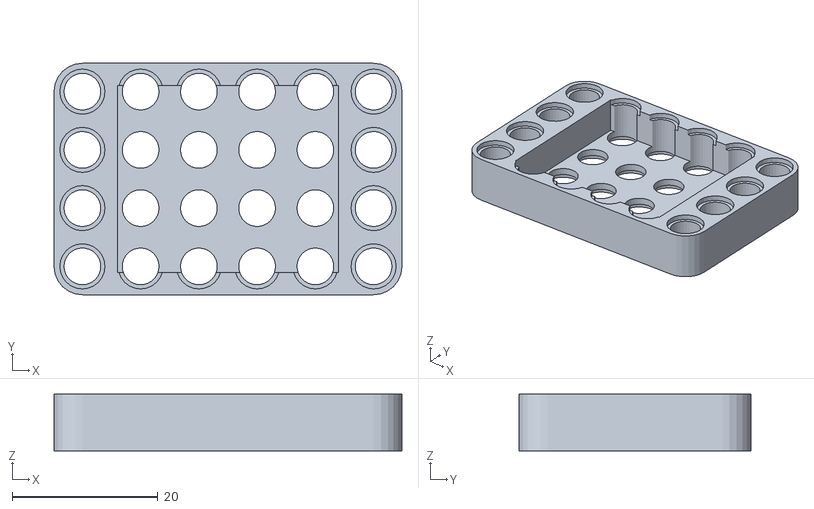
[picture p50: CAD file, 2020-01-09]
motor/PELA-esc-mount.stl
47.8 x 31.8 x 7.80

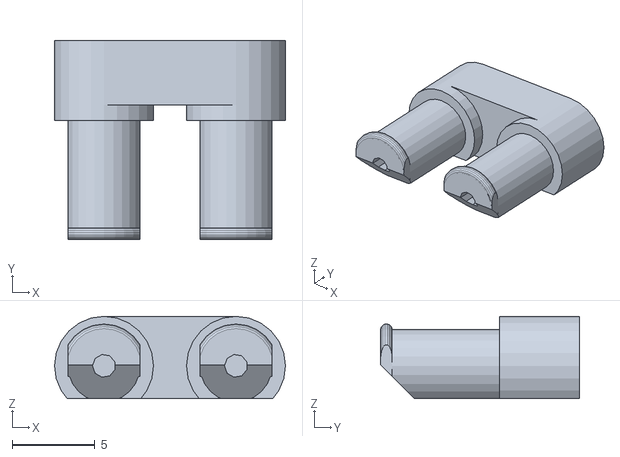
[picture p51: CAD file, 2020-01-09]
peg/PELA-technic-peg-array.stl
14.0 x 12.1 x 4.99

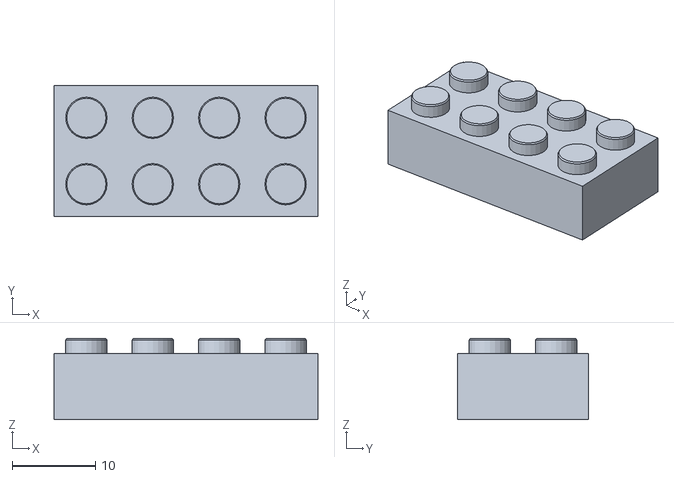
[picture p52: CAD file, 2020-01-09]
PELA-block.stl
31.8 x 15.8 x 9.80

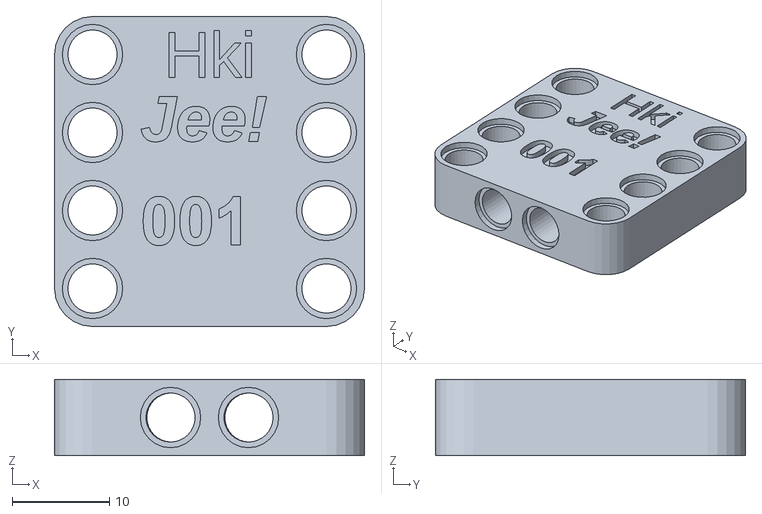
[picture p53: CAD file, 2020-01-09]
sign/PELA-technic-sign.stl
31.8 x 31.8 x 7.80

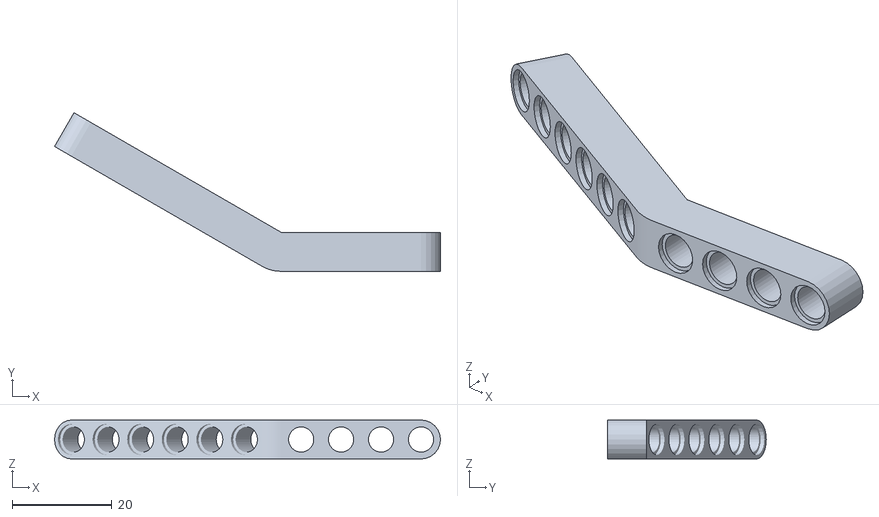
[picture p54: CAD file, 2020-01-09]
technic-beam/PELA-technic-bent-beam.stl
77.3 x 31.8 x 7.80

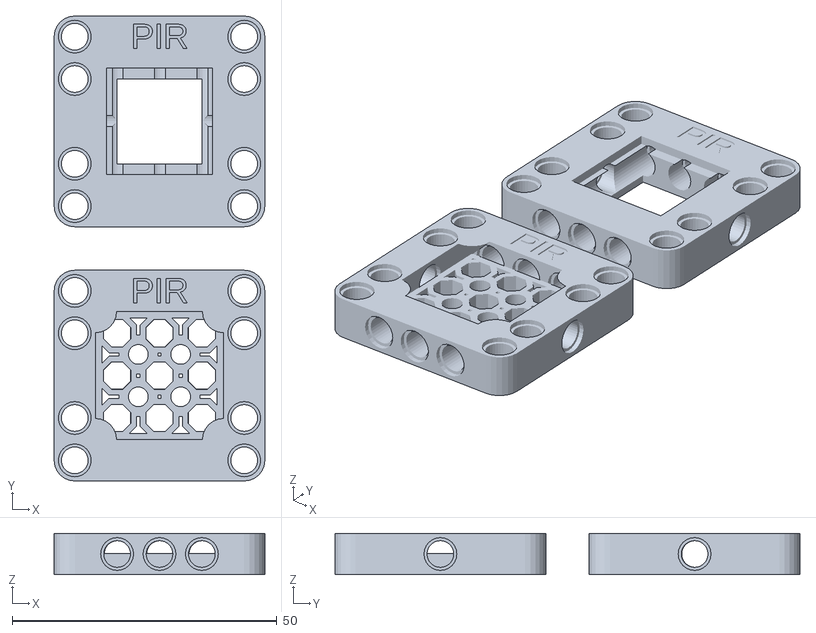
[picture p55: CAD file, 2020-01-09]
technic-mount/PELA-pir-technic-mount.stl
39.8 x 87.8 x 7.80

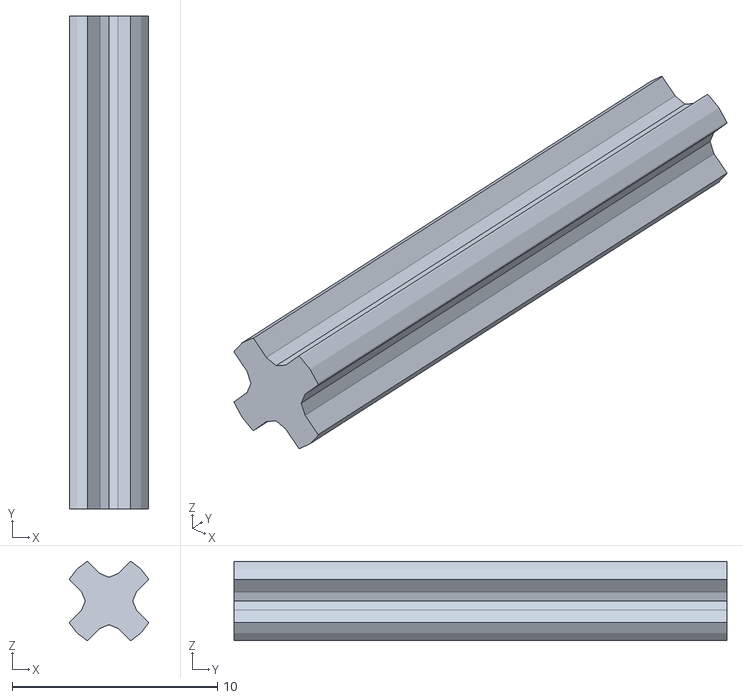
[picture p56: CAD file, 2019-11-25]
axle/PELA-technic-cross-axle.stl
3.86 x 24.0 x 3.86

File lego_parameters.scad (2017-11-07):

/*
Parametric LEGO Block Parameters

Published at
    http://www.thingiverse.com/thing:2303714
Maintained at
    https://github.com/paulirotta/parametric_lego
See also the related files
    LEGO Sign Generator - https://www.thingiverse.com/thing:2546028
    LEGO Enclosure Generator - https://www.thingiverse.com/thing:2544197


By Paul Houghton
Twitter: @mobile_rat
Email: paulirotta@gmail.com
Blog: https://medium.com/@paulhoughton

Creative Commons Attribution ShareAlike NonCommercial License
    https://creativecommons.org/licenses/by-sa/4.0/legalcode

Design work kindly sponsored by
    http://futurice.com

Import this into other design files to set baseline constants:
    include <lego_parameters.scad>
*/

/* [LEGO Basic Options] */

// What type of object to generate: 1=>block, 2=>block without top knobs, 3=>block without bottom connector, 4=>block without top knob or bottom connector
mode=1; // [1:1, 2:2, 3:3, 4:4]

// Length of the block (LEGO knob count)
l = 4; 

// Width of the block (LEGO knob count)
w = 3;

// Height of the block (LEGO brick layer count)
h = 1;

// Place holes in the corners of the panel for mountings screws (0=>no holes, 1=>holes)
bolt_holes=1; // [0:0, 1:1]

// Size of corner holes for mountings screws
bolt_hole_radius=1.5;

/* [3D Printing Adjustments] */

// Top connector size tweak => + = more tight fit, 0.06 for PLA, 0 for ABS, 0.07 for NGEN
top_tweak = 0;

// Bottom connector size tweak => + = more tight fit, -0.03 for PLA, 0 for ABS, -0.01 NGEN
bottom_tweak = 0;

// Height of the easy connect slope near connector top (0 to disable is standard a slightly faster to generate the model, a bigger value such as 0.4 may help if you adjust a tight fit but most printers' slicers will simplify away most usable bevels)
knob_bevel=0;

// Number of flexure cuts across the inside of each knob
knob_slice_count=0;

// Width of flexure cuts across the top of the knob
knob_slice_width=0.15;

// Length of the slice the knob from inside towards the edge
knob_slice_length_ratio=0.7;

/* [LEGO Technics] */

// Add full width through holes spaced along the length for LEGO Techics connectors (0=>no holes, 1=>simple air vents, 2=>single ended Technic connector, 3=>dual ended Technic connector)
side_holes = 1;  // [0:0, 1:1, 2:2, 3:3]

// Add a sheath around side holes (turn off for extra ventilation or rotating shafts)
side_hole_sheaths = 0; // [0:0, 1:1]

// Add short end holes spaced along the width for LEGO Techics connectors (0=>no holes, 1=>simple air vents, 2=>technics connector)
end_holes = 2;  // [0:0, 1:1, 2:2]

// Add a sheath around end holes (turn off for extra ventilation or rotating shafts)
end_hole_sheaths = 1; // [0:0, 1:1]

// Technic connector hole size tweak => + = more loose fit
bearing_hole_tweak = 0;


/* [Heat Ventilation] */

// Add holes in the top deck to improve airflow and reduce weight (0=>no holes, 1=>holes)
top_vents = 1;

// Size of a hole in the top of each knob to keep the cutout as part of the outside surface (slicer-friendly if knob_slice_count=0). Use a larger number for air circulation or to drain resin from the cutout, or 0 to disable.
knob_flexture_airhole_radius=0;

/* [Advanced] */

// Minimum angle to approximate a circle
$fa=6;

// Minimum segment length to approximate a circle
$fs=0.5;

// Clearance space on the outer surface of bricks
skin = 0.1; 

// Width of a line etched in the side of multi-layer block sets (0 to disable)
ridge_width = 0.15;

// Depth of a line etched in the side of multi-layer block sets
ridge_depth = 0.3;

// Distance below knob top surface and the internal cutout
knob_top_thickness=1;

// Size of the connectors
knob_radius=2.4;

// Height of the connectors (1.8 is Lego standard, longer valie like 2.4 gives a stronger hold while still maintaining compatibility)
knob_height=2.4;

// Size of the small flexture cavity inside each connector
knob_flexture_radius=1.5;

// Height of the hole beneath each knob
knob_flexture_height=4.55;

// Number of side to simulate a circle in the air hole and (smaller numbers render faster and are usually sufficient)
airhole_fn=16;

// Width of horizontal surface strengthening slats (usually between the bottom rings)
bottom_stiffener_width=3.8;

// Height of horizontal surface strengthening slats (appears between the bottom rings)
bottom_stiffener_height=4.5;

// Width of horizontal surface strengthening slats (usually between the bottom rings)
side_stiffener_width=0.8;

// Distance from inside walls which small stiffeners protrude inwards
side_stiffener_thickness=0.2;

// Basic unit horizonal size of LEGO
block_width=8;

// Basic unit vertial size of LEGO
block_height=9.6;

// Thickness of the solid outside surface of LEGO
block_shell=1.6; // thickness

// Depth which connectors may press into part bottom
socket_height= 8.6;

// Depth which the inside of connectors are hollowed out
socket_flexture_height= 7.4;

// Bottom connector assistance ring size
ring_radius=3.25;

/* [Advanced LEGO Technic Options] */

// Technic connector hole
bearing_hole_radius = 2.45;

// Technic connector inset radius
bearing_inset_radius = 3.1;

// Technic connector inset depth
bearing_inset_depth = 0.8;

// Technic connector additional depth when cut into a solid surface
bearing_inset_depth_clearance = 1;

// An axle which fits loosely in a technic bearing hole
technic_axle_radius = 2.4;

// How deep into a brick should a hole go before flaring out to grip
technic_bearing_length = 6.2;

// Size of an cylinder wrapped around the entrance to bearing holes
technic_sheath_thickness = 0.6;

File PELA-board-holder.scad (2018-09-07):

/*
PELA Board Holder - 3D Printed LEGO-compatible PCB mount

Published at https://driftcar.PELAblocks.org

By Paul Houghton
Twitter: @mobile_rat
Email: paulirotta@gmail.com
Blog: https://medium.com/@paulhoughton

Creative Commons Attribution ShareAlike NonCommercial License
    https://creativecommons.org/licenses/by-sa/4.0/legalcode

Design work kindly sponsored by
    https://www.futurice.com

All modules are setup for stateless functional-style reuse in other OpenSCAD files.
To this end, you can always pass in and override all parameters to create
a new effect. Doing this is not natural to OpenSCAD, so apologies for all
the boilerplate arguments which are passed in to each module or any errors
that may be hidden by the sensible default values. This is an evolving art.
*/

include <PELA-print-parameters.scad>
include <PELA-parameters.scad>
use <PELA-block.scad>
use <PELA-technic-block.scad>
use <box-enclosure/PELA-box-enclosure.scad>

////////////////////
// Parameters
////////////////////

length = 85;
width = 56;
thickness = 1.6;
undercut = 2.3; // How far below the bottom of the board surface parts protude (not indlucing big things like an SD card holder)
innercut = 0.8; // How far in from the outside edges the board support can extend without hitting board bottom surface parts
hold_d = 2.4;
bottom_type = 0;
top_vents = false;
side_holes = 2;
end_holes = 2;
side_sheaths = true;
end_sheaths = true;
left_wall_enabled = true;
right_wall_enabled = true;
front_wall_enabled = true;
back_wall_enabled = true;
drop_bottom = false;
knobs_on_top = true;
x_offset = 1.9;
y_offset = -3;
board_z_offset = -0.2;
sd_card_cutout_width = 16;
sd_card_cutout_depth = panel_height(2);


///////////
// Display
///////////

difference() {
    pcb_holder();
    union() {
        pcb_space();
        sd_card_cutout();
    }
}    


// Find the dimensions of the optimum holder based on board length or width
function fit_mm_to_pela_blocks(i) = ceil((i+block_width)/block_width);


module pcb_space() {
    l = fit_mm_to_pela_blocks(length);
    w = fit_mm_to_pela_blocks(width);
    x_inset = (block_width(l) - length)/2;
    y_inset = (block_width(w) - width)/2;
    translate([x_inset + x_offset, y_inset + y_offset, block_height()+board_z_offset]) {
        cube([length, width, thickness]);
    }

    // Undercut space for board bottom
    xu_inset = x_inset + innercut;
    yu_inset = y_inset + innercut;
    translate([xu_inset + x_offset, yu_inset + y_offset, block_height()+board_z_offset-undercut]) {
        #cube([length - 2*innercut, width - 2*innercut, undercut]);
    }
}


module pcb_space_skinned() {
    minkowski() {
        pcb_holder();
        sphere(r=0.1, $fn=8);
    }
}


module pcb_holder() {
    l = fit_mm_to_pela_blocks(length);
    w = fit_mm_to_pela_blocks(width);
    h = 1;
    left_wall_knobs = knobs_on_top;
    right_wall_knobs = false;
    front_wall_knobs = false;
    back_wall_knobs = knobs_on_top;

    PELA_box_enclosure(l=l, w=w, h=h, bottom_type=bottom_type, panel_height=panel_height, top_vents=top_vents, side_holes=side_holes, side_sheaths=side_sheaths, end_holes=end_holes, end_sheaths=end_sheaths, skin=skin, left_wall_enabled=left_wall_enabled, right_wall_enabled=right_wall_enabled, front_wall_enabled=front_wall_enabled, back_wall_enabled=back_wall_enabled, left_wall_knobs=left_wall_knobs, right_wall_knobs=right_wall_knobs, front_wall_knobs=front_wall_knobs, back_wall_knobs=back_wall_knobs, drop_bottom=drop_bottom, solid_upper_layers=solid_upper_layers, shell=shell);
}


module sd_card_cutout() {
    w = fit_mm_to_pela_blocks(width);
    translate([-0.1, (block_width(w)-sd_card_cutout_width)/2, block_height()-sd_card_cutout_depth]) {
        cube([block_width(2), sd_card_cutout_width, block_height(2)]);
    }
}

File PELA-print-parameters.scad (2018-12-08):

/*
Parametric PELA Print Tuning Parameters

Published at https://PELAblocks.org

By Paul Houghton
Twitter: @mobile_rat
Email: paulirotta@gmail.com
Blog: https://medium.com/@paulhoughton

Creative Commons Attribution-ShareAlike 4.0 International License
    https://creativecommons.org/licenses/by-sa/4.0/legalcode

Open source design, Powered By Futurice. Come work with the best.
    https://www.futurice.com/

Imported automatically into other design files when you include PELA_parameters:
    include <PELA_parameters.scad>
 

INSTRUCTIONS
============
1. Set 'flexible_material' and 'large_nozzle' below according to your printer.

2. Open 'PELA_calibration.scad' to generate and print the calibration .STL (In OpenSCAD press F6, then 'export').

3. Test fit the (a) top knobs, (b) bottom sockets, (c) technic holes on the side. These 3 numbers are your 'calibration'. Most slicer settings will not change the calibration for a given material, but use common sense and re-calibrate if needed.

4. Enter those numbers in this file.

5. Print a couple of 4x4 blocks with these adjusted parameters

6. Confirm your calibration fit with real PELA and between two printed blocks. All models will now adjust to this settings..


SUGGESTIONS
===========
- Don't waste time- use LEGO and LEGO technics to assemble what you need with a minimum of printed parts. Print the part yourself when you need something special (shape, function, material..).

- Make sure 'flexible_material' and 'large_nozzle' are set before you print the calibration block. These affect the size of flextures. All other numbers in this file are then set based on preference for a good fit of the calibration block to LEGO and other PELA pieces.

- Layer height is not important to PELA except for readable text on the sides of block

- Print PELA upright, or at up to 45 degrees tilt if needed. Avoid autogenerated supports inside the PELA block unless they are dissolvable.

- Printing fast is generally not a problem. PELA parts do need good inter-layer adhesion, so consider reducing the fan speed if this is a problem.

- Turn down the bed heater on low temperature materials like PLA to avoid "elephant foot" expansion of the bottom edges. Turn on 'brim, outside only' if you need more adhesion.

- Most printing materials are slippery. For this reason leave the top knobs at their default "taller than LEGO" setting to better grip. The downside is you can't push tall PELA knobs into a thin LEGO panel. You can adjust this in PELA-parmaeters.scad or in other cases disable knobs and focus on technic connections.

- Choose more flexible materials that are "tough" rather than stiff. TPU95 and Nylon are ideal and virtually indistructable. Brittle materials will not have as good a fit and may chip or crack. If you prefer PLA, you should try different brands- they vary considerably. Polymaker and Ultimaker PLA flex nicely.

- Smaller 0.4mm nozzles give better results. If 'large_nozzle' (>= 0.5mm) is true, the models will adjust the bottom socket geometry to make some of the inner structures thicker. If this is set wrong, then thin walls with a large nozzle may be eliminated by your slicer.

- See 'SLICER-RECOMMENDATIONS.md' for more tips and settings that have worked for us on specific materials.
*/

/* [Main Calibration Settings] */

// Switch between flexible and rigid material geometry. Set 'true' for Nylon, TPU (TPU95, Ninjaflex/TPU85), NGEN Semiflex and other flexible filaments. Subtle adjustments to part internal geometry will take advantage of this in flextures.
flexible_material = false;

// Set true if nozzle is >= 0.5mm. This simplifies the bottom gemoetry to create wider walls but at the cost of loosing the alternate bottom connector socket between every 4 other sockets. If not used with a large extruder the slicer may decimate features.
large_nozzle = true;

// Top knob size adjustment (larger is a stiffer fit, add in multiples of 0.01mm as determined from your calibration-block print)
top_tweak = -0.03; // -0.04 for ABS, 0.04 for rPET, -0.06 for Pro1, -0.08 for Polymaker Polylite PLA, -0.03 for NGEN, 0.02 for NGEN Flex, 0.09 for Ninjaflex, -0.02 for Bridge Nylon, 0.02 for Ultimaker TPU95A, 0.0 Biofila Silk

// Bottom connector size adjustment (smaller is tigher, add in multiples of 0.01mm as determined from your calibration-block print)
bottom_tweak = 0.08; // -0.02 for ABS, 0.10 for rPET, 0.08 for Pro1, 0.04 for Polymaker Polylite PLA, 0.08 for NGEN, 0.02 for NGEN Flex, -0.02 for Ninjaflex, 0.15 for Bridge Nylon, 0.04 for Ultimaker TPU95A, 0.0 Biofila Silk

// Side connector size adjustment (larger is a looser fit, add in multiples of 0.01mm as determined from your calibration-block print)
axle_hole_tweak = 0.05; // 0.05 for ABS, 0.04 for rPET, 0.04 for Pro1, 0.06 for Polymaker Polylite PLA, 0.05 for NGEN, 0 for NGEN Flex, 0.04 for Ninjaflex, 0.06 for Bridge Nylon, -0.06 for Ultimaker TPU95A, -0.04 Biofila Silk

// Generate print-time support aid structures for models which offer this. Turn this off if you will use slicer-generated print supports, but be aware that these may make the bottom connectors difficult to post process.
print_supports = true;

// In some models, the user will load two STL files into the slicer for a dual-material printer, one for each material/color. If "false" then the user wants a simplified, single material model
two_color_print = true;

// Add a text label to models which support that. The two_color_print setting will also affect if these is raised or colored text
text_labels = true;

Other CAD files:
technic-mount/PELA-technic-box.stl
vive-tracker/PELA-vive-tracker-mount.stl
motor/PELA-round-motor-enclosure.stl
peg/PELA-simplified-technic-peg-flexmaterial.stl
board-mount/PELA-arduino-mega-board-mount.scad
PELA-block.scad
PELA-box-enclosure.scad
PELA-calibration.scad
PELA-knob-mount.scad
PELA-knob-panel.scad
PELA-single-block.scad
PELA-socket-panel.scad
PELA-strap-mount.scad
PELA-strap-mount.stl
PELA-technic-block.scad
PELA-technic-block.stl
axle/PELA-technic-axle.scad
axle/PELA-technic-axle.stl
axle/PELA-technic-cross-axle.scad
axle/PELA-technic-hub.scad
axle/PELA-technic-wheel.scad
board-mount/PELA-esp32-board-mount.scad
board-mount/PELA-esp8266-board-mount.scad
board-mount/PELA-nodemcu-32s-board-mount.scad
board-mount/PELA-nodemcu-v2-board-mount.scad
board-mount/PELA-pca9685-servo-board-mount.scad
board-mount/PELA-raspberry-pi3-board-mount.scad
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

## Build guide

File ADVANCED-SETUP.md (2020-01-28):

# PELA Blocks

See also the [Slicer Recommendations](SLICER_RECOMMENDATIONS) printing information.

## Advanced Setup

Instructions are for Windows, however Linux and OSX are esssentially the same but scripts to automate batch building are not provided.

## Backing Up Your Calibration Files

Copy your calibration files and any .json parameter adjustment files you have created to another directory before update to a newer version of PELA-blocks, you might overwrite your calibration customizations. 

1. `cd PELA-blocks`
1. `cp material.scad ..`
1. `cp *.json ..`

## GIT LFS

You may need to install git lfs separately.

1. `git lfs install`
=======

## Sparce Checkout

This saves space on your computer, bandwidth and time. Only the latest version of generated STL and PNG images is kept locally.

1. `git config core.sparcecheckout true`

## Compress and clean STL files from the command line

OpenSCAD exports large text files which 2x larger than binary STL. They may also contain mistakes (non-manifold, etc). Usually your slicer can handle this just fine.

Cleaning and compressing the STL before slicing is optional but may help if you Slicer complains about the file. A quick solution is to load and re-save the file generated by OpenSCAD in [Windows 3D Builder](https://www.microsoft.com/store/apps/9wzdncrfj3t6) (Open the file, Click `YES` to fix, then `CTRL S` to save over the original file), [Meshlab](http://www.meshlab.net/) or [Meshmixer](http://www.meshmixer.com/download.html).

It is also possible to setup a batch process to clean and re-save multiple `.STL` files using Meshlab. We used to do this but simplified it away as it adds little value. If you know of a better batch tool for cleaning files, please let us know.

## Cleaning up git

Github kindly gives us LFS but no tools for removing old files on LFS. So to keep the size down, occational cleanup is in the following script which runs on both Linux and Windows.

1. `./gitcleanup.ps1`

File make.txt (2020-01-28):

Render image motor/PELA-n20-gearmotor-enclosure.scad
motor/PELA-n20-gearmotor-enclosure.png preview image error: ERROR: Parser error in file "/home/paul/github/PELA-drift-car/PELA-blocks/motor/PELA-n20-gearmotor-enclosure.scad", line 34: syntax error

Can't parse file 'motor/PELA-n20-gearmotor-enclosure.scad'!

Render stl PELA-grove-module-enclosure.scad
PELA-grove-module-enclosure.scad model build error: ERROR: Assertion '(skin != undef)' failed in file PELA-technic-block.scad, line 432
TRACE: called by 'assert', in file PELA-technic-block.scad, line 432.
TRACE: called by 'double_end_connector_hole_set', in file PELA-grove-module-enclosure.scad, line 175.
TRACE: called by 'union', in file PELA-grove-module-enclosure.scad, line 168.
TRACE: called by 'difference', in file PELA-grove-module-enclosure.scad, line 161.
TRACE: called by 'bottom_piece', in file PELA-grove-module-enclosure.scad, line 138.
TRACE: called by 'if', in file PELA-grove-module-enclosure.scad, line 137.
TRACE: called by 'rotate', in file PELA-grove-module-enclosure.scad, line 136.
TRACE: called by 'grove_module_enclosure', in file PELA-grove-module-enclosure.scad, line 129.
Current top level object is empty.

sign/PELA-vertical-sign.scad model build error: WARNING: Ignoring unknown variable 'material', in file PELA-vertical-sign.scad, line 134.
WARNING: Ignoring unknown variable 'material', in file PELA-vertical-sign.scad, line 126.
ERROR: Assertion '(material != undef)' failed in file PELA-technic-block.scad, line 144
TRACE: called by 'assert', in file PELA-technic-block.scad, line 144.
TRACE: called by 'PELA_technic_block', in file PELA-vertical-sign.scad, line 138.
TRACE: called by 'if', in file PELA-vertical-sign.scad, line 137.
TRACE: called by 'difference', in file PELA-vertical-sign.scad, line 136.
TRACE: called by 'PELA_vertical_sign', in file PELA-vertical-sign.scad, line 126.
Current top level object is empty.

Render stl knob-mount/PELA-knob-mount.scad
knob-mount/PELA-knob-mount.scad model build error: WARNING: Ignoring unknown variable 'skip_edge_knobs', in file PELA-knob-mount.scad, line 316.
WARNING: Ignoring unknown variable 'knob_vent_radius', in file PELA-knob-mount.scad, line 316.
ERROR: Assertion '(knob_height != undef)' failed in file PELA-box-enclosure.scad, line 252
TRACE: called by 'assert', in file PELA-box-enclosure.scad, line 252.
TRACE: called by 'box_enclosure', in file PELA-knob-mount.scad, line 316.
TRACE: called by 'difference', in file PELA-knob-mount.scad, line 315.
TRACE: called by 'knob_mount', in file PELA-knob-mount.scad, line 244.
Current top level object is empty.

Render stl knob-mount/PELA-nodemcu-32s-knob-mount.scad
knob-mount/PELA-nodemcu-32s-knob-mount.scad model build error: WARNING: Ignoring unknown variable 'block_height', in file PELA-nodemcu-32s-knob-mount.scad, line 130.
WARNING: Ignoring unknown variable 'material', in file PELA-nodemcu-32s-knob-mount.scad, line 130.
ERROR: Assertion '(material != undef)' failed in file PELA-knob-mount.scad, line 254
TRACE: called by 'assert', in file PELA-knob-mount.scad, line 254.
TRACE: called by 'knob_mount', in file PELA-nodemcu-32s-knob-mount.scad, line 140.
TRACE: called by 'difference', in file PELA-nodemcu-32s-knob-mount.scad, line 139.
TRACE: called by 'nodemcu_32s_knob_mount', in file PELA-nodemcu-32s-knob-mount.scad, line 130.
Current top level object is empty.

Render stl knob-mount/PELA-nodemcu-v2-knob-mount.scad
knob-mount/PELA-nodemcu-v2-knob-mount.scad model build error: WARNING: Ignoring unknown variable 'material', in file PELA-nodemcu-v2-knob-mount.scad, line 142.
ERROR: Assertion '(material != undef)' failed in file PELA-knob-mount.scad, line 254
TRACE: called by 'assert', in file PELA-knob-mount.scad, line 254.
TRACE: called by 'knob_mount', in file PELA-nodemcu-v2-knob-mount.scad, line 153.
TRACE: called by 'difference', in file PELA-nodemcu-v2-knob-mount.scad, line 152.
TRACE: called by 'nodemcu_v2_knob_mount', in file PELA-nodemcu-v2-knob-mount.scad, line 142.
Current top level object is empty.

Render stl knob-mount/PELA-pca9685-servo-knob-mount.scad
knob-mount/PELA-pca9685-servo-knob-mount.scad model build error: WARNING: Ignoring unknown variable 'block_height', in file PELA-pca9685-servo-knob-mount.scad, line 133.
WARNING: Ignoring unknown variable 'material', in file PELA-pca9685-servo-knob-mount.scad, line 133.
WARNING: Ignoring unknown variable 'sockets', in file PELA-pca9685-servo-knob-mount.scad, line 133.
ERROR: Assertion '(material != undef)' failed in file PELA-knob-mount.scad, line 254
TRACE: called by 'assert', in file PELA-knob-mount.scad, line 254.
TRACE: called by 'knob_mount', in file PELA-pca9685-servo-knob-mount.scad, line 133.
Current top level object is empty.

Render stl knob-mount/PELA-sparkfun-pro-micro-knob-mount.scad
knob-mount/PELA-sparkfun-pro-micro-knob-mount.scad model build error: WARNING: Ignoring unknown variable 'block_height', in file PELA-sparkfun-pro-micro-knob-mount.scad, line 126.
WARNING: Ignoring unknown variable 'material', in file PELA-sparkfun-pro-micro-knob-mount.scad, line 126.
ERROR: Assertion '(material != undef)' failed in file PELA-knob-mount.scad, line 254
TRACE: called by 'assert', in file PELA-knob-mount.scad, line 254.
TRACE: called by 'knob_mount', in file PELA-sparkfun-pro-micro-knob-mount.scad, line 137.
TRACE: called by 'difference', in file PELA-sparkfun-pro-micro-knob-mount.scad, line 136.
TRACE: called by 'PELA_sparkfun_pro_micro_knob_mount', in file PELA-sparkfun-pro-micro-knob-mount.scad, line 126.
Current top level object is empty.

motor/PELA-n20-gearmotor-enclosure.scad model build error: ERROR: Parser error in file "/home/paul/github/PELA-drift-car/PELA-blocks/motor/PELA-n20-gearmotor-enclosure.scad", line 34: syntax error

Can't parse file 'motor/PELA-n20-gearmotor-enclosure.scad'!

Render stl motor/PELA-round-motor-enclosure.scad
axle/PELA-technic-axle.scad model build error: ERROR: Assertion '(skin != undef)' failed in file PELA-block.scad, line 135
TRACE: called by 'assert', in file PELA-block.scad, line 135.
TRACE: called by 'cut_space', in file PELA-technic-axle.scad, line 83.
TRACE: called by 'translate', in file PELA-technic-axle.scad, line 82.
TRACE: called by 'union', in file PELA-technic-axle.scad, line 77.
TRACE: called by 'difference', in file PELA-technic-axle.scad, line 74.
TRACE: called by 'axle', in file PELA-technic-axle.scad, line 54.
Current top level object is empty.

Render stl axle/PELA-technic-cross-axle.scad
axle/PELA-technic-cross-axle.scad model build error: ERROR: Assertion '(skin != undef)' failed in file PELA-block.scad, line 135
TRACE: called by 'assert', in file PELA-block.scad, line 135.
TRACE: called by 'cut_space', in file PELA-technic-axle.scad, line 83.
TRACE: called by 'translate', in file PELA-technic-axle.scad, line 82.
TRACE: called by 'union', in file PELA-technic-axle.scad, line 77.
TRACE: called by 'difference', in file PELA-technic-axle.scad, line 74.
TRACE: called by 'axle', in file PELA-technic-cross-axle.scad, line 77.
TRACE: called by 'difference', in file PELA-technic-cross-axle.scad, line 76.
TRACE: called by 'rotate', in file PELA-technic-cross-axle.scad, line 75.
TRACE: called by 'cross_axle', in file PELA-technic-cross-axle.scad, line 54.
Current top level object is empty.

Render stl axle/PELA-technic-hub.scad
axle/PELA-technic-hub.scad model build error: ECHO: "hub_radius: ", 4
ERROR: Assertion '(skin != undef)' failed in file PELA-block.scad, line 135
TRACE: called by 'assert', in file PELA-block.scad, line 135.
TRACE: called by 'cut_space', in file PELA-technic-axle.scad, line 83.
TRACE: called by 'translate', in file PELA-technic-axle.scad, line 82.
TRACE: called by 'union', in file PELA-technic-axle.scad, line 77.
TRACE: called by 'difference', in file PELA-technic-axle.scad, line 74.
TRACE: called by 'axle', in file PELA-technic-cross-axle.scad, line 77.
TRACE: called by 'difference', in file PELA-technic-cross-axle.scad, line 76.
TRACE: called by 'rotate', in file PELA-technic-cross-axle.scad, line 75.
TRACE: called by 'cross_axle', in file PELA-technic-hub.scad, line 88.
TRACE: called by 'rotate', in file PELA-technic-hub.scad, line 87.
TRACE: called by 'translate', in file PELA-technic-hub.scad, line 86.
TRACE: called by 'difference', in file PELA-technic-hub.scad, line 83.
Current top level object is empty.

Render stl axle/PELA-technic-wheel.scad
axle/PELA-technic-wheel.scad model build error: ECHO: "hub_radius: ", 4
ERROR: Assertion '(skin != undef)' failed in file PELA-block.scad, line 135
TRACE: called by 'assert', in file PELA-block.scad, line 135.
TRACE: called by 'cut_space', in file PELA-technic-axle.scad, line 83.
TRACE: called by 'translate', in file PELA-technic-axle.scad, line 82.
TRACE: called by 'union', in file PELA-technic-axle.scad, line 77.
TRACE: called by 'difference', in file PELA-technic-axle.scad, line 74.
TRACE: called by 'axle', in file PELA-technic-cross-axle.scad, line 77.
TRACE: called by 'difference', in file PELA-technic-cross-axle.scad, line 76.
TRACE: called by 'rotate', in file PELA-technic-cross-axle.scad, line 75.
TRACE: called by 'cross_axle', in file PELA-technic-hub.scad, line 88.
TRACE: called by 'rotate', in file PELA-technic-hub.scad, line 87.
TRACE: called by 'translate', in file PELA-technic-hub.scad, line 86.
TRACE: called by 'difference', in file PELA-technic-hub.scad, line 83.
Current top level object is empty.

Render stl knob-mount/PELA-arduino-mega-knob-mount.scad
knob-mount/PELA-arduino-mega-knob-mount.scad model build error: ERROR: Assertion '(bottom_vents != undef)' failed in file PELA-knob-mount.scad, line 267
TRACE: called by 'assert', in file PELA-knob-mount.scad, line 267.
TRACE: called by 'knob_mount', in file PELA-arduino-mega-knob-mount.scad, line 240.
Current top level object is empty.

Render stl knob-mount/PELA-box-enclosure.scad
PNG render complete: technic-mount/PELA-t265-realsense-tracking-camera-technic-mount.scad
Render image technic-mount/PELA-technic-box.scad
STL render complete: motor/PELA-round-motor-enclosure.scad
Render stl motor/PELA-square-servo-end-mount.scad
motor/PELA-square-servo-end-mount.scad model build error: WARNING: variable skin not specified as parameter, in file PELA-square-servo-end-mount.scad, line 153
ERROR: Assertion '(horizontal_skin != undef)' failed in file PELA-technic-beam.scad, line 85
TRACE: called by 'assert', in file PELA-technic-beam.scad, line 85.
TRACE: called by 'technic_beam', in file PELA-square-servo-end-mount.scad, line 153.
TRACE: called by 'square_servo_end_beam', in file PELA-square-servo-end-mount.scad, line 131.
TRACE: called by 'color', in file PELA-square-servo-end-mount.scad, line 131.
TRACE: called by 'difference', in file PELA-square-servo-end-mount.scad, line 129.
TRACE: called by 'square_servo_end_mount', in file PELA-square-servo-end-mount.scad, line 101.
Current top level object is empty.

Render stl pin/PELA-technic-pin-array.scad
pin/PELA-technic-pin-array.scad model build error: ERROR: Assertion '(skin != undef)' failed in file PELA-block.scad, line 135
TRACE: called by 'assert', in file PELA-block.scad, line 135.
TRACE: called by 'cut_space', in file PELA-technic-pin.scad, line 130.
TRACE: called by 'translate', in file PELA-technic-pin.scad, line 129.
TRACE: called by 'union', in file PELA-technic-pin.scad, line 110.
TRACE: called by 'difference', in file PELA-technic-pin.scad, line 95.
TRACE: called by 'rotate', in file PELA-technic-pin.scad, line 94.
TRACE: called by 'translate', in file PELA-technic-pin.scad, line 93.
TRACE: called by 'difference', in file PELA-technic-pin.scad, line 92.
TRACE: called by 'pin', in file PELA-technic-pin.scad, line 264.
TRACE: called by 'translate', in file PELA-technic-pin.scad, line 263.
TRACE: called by 'for', in file PELA-technic-pin.scad, line 262.
TRACE: called by 'difference', in file PELA-technic-pin.scad, line 261.
Current top level object is empty.

Render stl pin/PELA-technic-pin.scad
pin/PELA-technic-pin.scad model build error: ERROR: Assertion '(skin != undef)' failed in file PELA-block.scad, line 135
TRACE: called by 'assert', in file PELA-block.scad, line 135.
TRACE: called by 'cut_space', in file PELA-technic-pin.scad, line 130.
TRACE: called by 'translate', in file PELA-technic-pin.scad, line 129.
TRACE: called by 'union', in file PELA-technic-pin.scad, line 110.
TRACE: called by 'difference', in file PELA-technic-pin.scad, line 95.
TRACE: called by 'rotate', in file PELA-technic-pin.scad, line 94.
TRACE: called by 'translate', in file PELA-technic-pin.scad, line 93.
TRACE: called by 'difference', in file PELA-technic-pin.scad, line 92.
TRACE: called by 'pin', in file PELA-technic-pin.scad, line 54.
Current top level object is empty.

Render stl sign/PELA-panel-sign.scad
sign/PELA-panel-sign.scad model build error: DEPRECATED: Using ranges of the form [begin:end] with begin value greater than the end value is deprecated.
ERROR: Assertion '(skin != undef)' failed in file PELA-block.scad, line 135
TRACE: called by 'assert', in file PELA-block.scad, line 135.
TRACE: called by 'cut_space', in file PELA-panel-sign.scad, line 173.
TRACE: called by 'difference', in file PELA-panel-sign.scad, line 153.
TRACE: called by 'PELA_panel_sign', in file PELA-panel-sign.scad, line 117.
Current top level object is empty.

Render stl sign/PELA-technic-sign.scad
sign/PELA-technic-sign.scad model build error: WARNING: variable knob_vent_radius not specified as parameter, in file PELA-technic-sign.scad, line 142
WARNING: variable solid_first_layer not specified as parameter, in file PELA-technic-sign.scad, line 142
WARNING: variable sockets not specified as parameter, in file PELA-technic-sign.scad, line 185
WARNING: variable knobs not specified as parameter, in file PELA-technic-sign.scad, line 185
WARNING: variable solid_first_layer not specified as parameter, in file PELA-technic-sign.scad, line 185
ERROR: Assertion '(top_vents != undef)' failed in file PELA-technic-box.scad, line 176
TRACE: called by 'assert', in file PELA-technic-box.scad, line 176.
TRACE: called by 'technic_box', in file PELA-technic-sign.scad, line 185.
TRACE: called by 'difference', in file PELA-technic-sign.scad, line 184.
TRACE: called by 'union', in file PELA-technic-sign.scad, line 183.
TRACE: called by 'difference', in file PELA-technic-sign.scad, line 182.
TRACE: called by 'PELA_technic_sign', in file PELA-technic-sign.scad, line 142.
Current top level object is empty.

Render stl technic-mount/PELA-respeaker-core-v2-mount.scad
technic-mount/PELA-respeaker-core-v2-mount.scad model build error: WARNING: Ignoring unknown variable 'width', in file PELA-respeaker-core-v2-mount.scad, line 74.
WARNING: Ignoring unknown variable 'side', in file PELA-respeaker-core-v2-mount.scad, line 76.
WARNING: Ignoring unknown variable 'side', in file PELA-respeaker-core-v2-mount.scad, line 76.
WARNING: Ignoring unknown variable 'side_length', in file PELA-respeaker-core-v2-mount.scad, line 95.
WARNING: Ignoring unknown variable 'outer_width', in file PELA-respeaker-core-v2-mount.scad, line 97.
WARNING: Ignoring unknown variable 'side', in file PELA-respeaker-core-v2-mount.scad, line 97.
WARNING: Ignoring unknown variable 'side', in file PELA-respeaker-core-v2-mount.scad, line 97.
WARNING: Ignoring unknown variable 'width', in file PELA-respeaker-core-v2-mount.scad, line 108.
WARNING: Ignoring unknown variable 'top', in file PELA-respeaker-core-v2-mount.scad, line 110.
WARNING: Ignoring unknown variable 'top', in file PELA-respeaker-core-v2-mount.scad, line 115.
WARNING: Ignoring unknown variable 'material', in file PELA-respeaker-core-v2-mount.scad, line 277.
WARNING: Ignoring unknown variable 'ox', in file PELA-respeaker-core-v2-mount.scad, line 279.
WARNING: Ignoring unknown variable 'oy', in file PELA-respeaker-core-v2-mount.scad, line 279.
WARNING: Ignoring unknown variable 'board_model', in file PELA-respeaker-core-v2-mount.scad, line 280.
WARNING: Ignoring unknown variable 'side_length', in file PELA-respeaker-core-v2-mount.scad, line 290.
ERROR: Assertion '(material != undef)' failed in file PELA-technic-beam.scad, line 82
TRACE: called by 'assert', in file PELA-technic-beam.scad, line 82.
TRACE: called by 'technic_beam', in file PELA-respeaker-core-v2-mount.scad, line 290.
TRACE: called by 'color', in file PELA-respeaker-core-v2-mount.scad, line 289.
TRACE: called by 'rotate', in file PELA-respeaker-core-v2-mount.scad, line 287.
TRACE: called by 'respeaker_core_v2_technic_mount', in file PELA-respeaker-core-v2-mount.scad, line 138.
TRACE: called by 'rotate', in file PELA-respeaker-core-v2-mount.scad, line 137.
TRACE: called by 'if', in file PELA-respeaker-core-v2-mount.scad, line 136.
Current top level object is empty.

Render stl technic-mount/PELA-respeaker-mic-array-v2-technic-mount.scad
technic-mount/PELA-respeaker-mic-array-v2-technic-mount.scad model build error: WARNING: variable center_sockets not specified as parameter, in file PELA-respeaker-mic-array-v2-technic-mount.scad, line 220
WARNING: variable center_knobs not specified as parameter, in file PELA-respeaker-mic-array-v2-technic-mount.scad, line 220
WARNING: variable cover_sockets not specified as parameter, in file PELA-respeaker-mic-array-v2-technic-mount.scad, line 220
WARNING: variable cover_knobs not specified as parameter, in file PELA-respeaker-mic-array-v2-technic-mount.scad, line 220
WARNING: variable solid_first_layer not specified as parameter, in file PELA-respeaker-mic-array-v2-technic-mount.scad, line 220
WARNING: Ignoring unknown variable 'material', in file PELA-respeaker-mic-array-v2-technic-mount.scad, line 220.
WARNING: Ignoring unknown variable 'solid_first_layer', in file PELA-respeaker-mic-array-v2-technic-mount.scad, line 220.
ERROR: Assertion '(material != undef)' failed in file PELA-technic-mount.scad, line 232
TRACE: called by 'assert', in file PELA-technic-mount.scad, line 232.
TRACE: called by 'technic_mount_and_cover', in file PELA-respeaker-mic-array-v2-technic-mount.scad, line 220.
TRACE: called by 'difference', in file PELA-respeaker-mic-array-v2-technic-mount.scad, line 219.
Current top level object is empty.

Render stl technic-mount/PELA-sparkfun-bigeasydriver-technic-mount.scad
technic-mount/PELA-sparkfun-bigeasydriver-technic-mount.scad model build error: WARNING: variable center_sockets not specified as parameter, in file PELA-sparkfun-bigeasydriver-technic-mount.scad, line 209
WARNING: variable center_knobs not specified as parameter, in file PELA-sparkfun-bigeasydriver-technic-mount.scad, line 209
WARNING: variable cover_sockets not specified as parameter, in file PELA-sparkfun-bigeasydriver-technic-mount.scad, line 209
WARNING: variable cover_knobs not specified as parameter, in file PELA-sparkfun-bigeasydriver-technic-mount.scad, line 209
WARNING: variable solid_first_layer not specified as parameter, in file PELA-sparkfun-bigeasydriver-technic-mount.scad, line 209
WARNING: Ignoring unknown variable 'horizontal_skin', in file PELA-sparkfun-bigeasydriver-technic-mount.scad, line 209.
WARNING: Ignoring unknown variable 'material', in file PELA-sparkfun-bigeasydriver-technic-mount.scad, line 209.
WARNING: Ignoring unknown variable 'solid_first_layer', in file PELA-sparkfun-bigeasydriver-technic-mount.scad, line 209.
WARNING: Ignoring unknown variable 'vertical_skin', in file PELA-sparkfun-bigeasydriver-technic-mount.scad, line 209.
WARNING: Ignoring unknown variable 'knob_vent_radius', in file PELA-sparkfun-bigeasydriver-technic-mount.scad, line 209.
ERROR: Assertion '(material != undef)' failed in file PELA-technic-mount.scad, line 232
TRACE: called by 'assert', in file PELA-technic-mount.scad, line 232.
TRACE: called by 'technic_mount_and_cover', in file PELA-sparkfun-bigeasydriver-technic-mount.scad, line 209.
TRACE: called by 'difference', in file PELA-sparkfun-bigeasydriver-technic-mount.scad, line 208.
Current top level object is empty.

Render stl technic-mount/PELA-stmf4-discovery-technic-mount.scad
STL render complete: knob-mount/PELA-box-enclosure.scad
Render stl knob-mount/PELA-intel-compute-stick-box-enclosure.scad
knob-mount/PELA-intel-compute-stick-box-enclosure.scad model build error: WARNING: _h was assigned on line 54 but was overwritten on line 84
WARNING: Ignoring unknown variable 'l_pad', in file PELA-intel-compute-stick-box-enclosure.scad, line 259.
WARNING: Ignoring unknown variable 'length', in file PELA-intel-compute-stick-box-enclosure.scad, line 259.
WARNING: ceil() parameter could not be converted, in file ../PELA-technic-block.scad, line 130
WARNING: Ignoring unknown variable 'w_pad', in file PELA-intel-compute-stick-box-enclosure.scad, line 260.
WARNING: Ignoring unknown variable 'width', in file PELA-intel-compute-stick-box-enclosure.scad, line 260.
WARNING: ceil() parameter could not be converted, in file ../PELA-technic-block.scad, line 130
WARNING: Ignoring unknown variable 'length', in file PELA-intel-compute-stick-box-enclosure.scad, line 207.
ERROR: Assertion '(length != undef)' failed in file PELA-intel-compute-stick-box-enclosure.scad, line 207
TRACE: called by 'assert', in file PELA-intel-compute-stick-box-enclosure.scad, line 207.
TRACE: called by 'intel_compute_stick_box_enclosure', in file PELA-intel-compute-stick-box-enclosure.scad, line 195.
Current top level object is empty.

Render stl technic-mount/PELA-pir-technic-mount.scad
STL render complete: technic-mount/PELA-nodemcu-v2-technic-mount.scad
Render stl technic-mount/PELA-pca9685-servo-board-technic-mount.scad
PNG render complete: technic-mount/PELA-arduino-uno-technic-mount.scad
Render image technic-mount/PELA-jetson-nano-technic-mount.scad
PNG render complete: technic-mount/PELA-technic-mount.scad
Render stl technic-mount/PELA-powerbank-technic-mount.scad
STL render complete: technic-mount/PELA-pir-technic-mount.scad
Render stl threads/Yet_another_thread_library_for_OpenSCAD/quickthread.scad
threads/Yet_another_thread_library_for_OpenSCAD/quickthread.scad model build error: Current top level object is empty.

Render stl threads/threads.scad
threads/threads.scad model build error: Current top level object is empty.

Render stl vive-tracker/PELA-camera-mount-screw.scad
vive-tracker/PELA-camera-mount-screw.scad model build error: ERROR: Assertion '(skin != undef)' failed in file PELA-block.scad, line 135
TRACE: called by 'assert', in file PELA-block.scad, line 135.
TRACE: called by 'cut_space', in file PELA-camera-mount-screw.scad, line 98.
TRACE: called by 'translate', in file PELA-camera-mount-screw.scad, line 97.
TRACE: called by 'difference', in file PELA-camera-mount-screw.scad, line 86.
TRACE: called by 'thumbscrew', in file PELA-camera-mount-screw.scad, line 64.
Current top level object is empty.

Render stl vive-tracker/PELA-vive-tracker-mount.scad
vive-tracker/PELA-vive-tracker-mount.scad model build error: WARNING: variable solid_first_layer not specified as parameter, in file PELA-vive-tracker-mount.scad, line 140
ERROR: Assertion '(skin != undef)' failed in file PELA-socket-panel.scad, line 84
TRACE: called by 'assert', in file PELA-socket-panel.scad, line 84.
TRACE: called by 'socket_panel', in file PELA-vive-tracker-mount.scad, line 140.
TRACE: called by 'union', in file PELA-vive-tracker-mount.scad, line 139.
TRACE: called by 'difference', in file PELA-vive-tracker-mount.scad, line 138.
TRACE: called by 'PELA_vive_tracker_mount', in file PELA-vive-tracker-mount.scad, line 119.
Current top level object is empty.

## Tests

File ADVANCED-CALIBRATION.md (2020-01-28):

# PELA Blocks
## Advanced Calibration

## Backing Up Your Calibration Files

If you later update the PELA-blocks project to a newer version, you risk overwirting and loosing your calibration customizations. The simplest solution is to create a backup copy those settings.

1. `cd PELA-Blocks`
1. `cp style.scad ../PELA-parameters-backup.scad`
1. `cp material.scad ../PELA-print-parameters-backup.scad`

## Calibration Block Set (optional)

PELA Calibration Set

[PELA Calibration Block Set](https://github.com/LEGO-Prototypes/PELA-blocks/blob/master/PELA-calibration-set.stl)

These individual blocks provide technic hole size calibration and can be used more flexibly. The technic holes vary in size. Enter the desired number as `axle_hole_tweak` in [`material.scad`](material.scad)

## Other Parameters (optional)

Other parametric model parameters affecting all designs are available in [`style.scad`](style.scad). The effect of each setting is documented, or you can test the effect by changing the number and observing the result.

## CAD File Organization

All models include `material.scad` and `style.scad` directly. Most also include `PELA-block.scad` and `PELA-technic-block.scad`. When you make changes to these files and save to disk, the preview imnage will update automatically. Press `F6` for a more accurate rendering.

OpenSCAD modules accept parameters which you can change to get various effects and shapes. Default values are set in the files. Call the module with only the parameters you are setting away from the default.

OpenSCAD treats a variable values passed in from the command line is a constant. This constant value overrides the defaults in the file. You can find examples of this in `PELA-block.scad`.

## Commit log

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2017-09-18 Added LEGO calibration block set for testing the parameters needed on a given printer and plastic to get a tight fit Added LEGO panel builder with corner screw holes Minor updates and tweaks Changed 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
    [lego.scad]
2017-09-19 Changed generic inner enclosure directory References to upper dir <lego.scad> Passing $fn as an argument into lego modules Enclosure now builds as an end
    TODO The skins on the bottom are not clean
    [enclosure.scad, lego.scad]
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2017-09-20 Updated the parametric Lego enclosure Fixed the Lego panel knob hole diameters More consistent use of default values in several places Added a Thingiverse customizer-compatible copy of the parametric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
    [enclosure.scad, parametric-lego-enclosure-thingiverse.scad, parametric-lego-enclosure.scad]
2017-09-20 Added more generated STL files of pre-build variants Parametric LEGO Enclosure now references the correct thing numbers on Thingiverse
    [lego.scad, parametric-lego-enclosure-thingiverse.scad, parametric-lego-enclosure.scad]
2017-09-20 Lego enclosure STL versions in the 90 degree rotation for printing orientation generated
    [parametric-lego-enclosure.scad]
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2017-09-21 Parametric sign has text properly centered Parametric sign taxt copy_to_back option added Parametric sign extrude and etch options supported
    [parametric-lego-enclosure-thingiverse.scad, parametric-lego-enclosure.scad, parametric-lego-sign-thingiverse.scad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]
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2017-09-21 Updated parametric sign online customizer to use string "true" instead of boolean Links in comments updated
    [lego.scad, parametric-lego-enclosure-thingiverse.scad, parametric-lego-enclosure.scad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]
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2017-09-22 Updated the documented recommendation size for PLA More clear labeling of the size tweak variables
    [lego.scad, parametric-lego-enclosure-thingiverse.scad, parametric-lego-enclosure.scad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]
2017-09-22 Lower extrusion text depth for better ABS print quality (less likely to punch through the back due to print quality) Updated STLs generated by Parametric sign
    [parametric-lego-sign-thingiverse.scad, parametric-lego-sign.scad]
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2017-09-26 Added a hole below each knob to test flex of fit
    [lego.scad]
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2017-09-27 Updates to simplify defaults in lego block Command line STL generator script (incomplete)
    [lego.scad, parametric-lego-enclosure-thingiverse.scad, parametric-lego-enclosure.scad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]
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2017-09-29 Better through-hole under the knob Performance optimization, removing unneeded airole in panels etc More clear panel thickness parameter
    [command-line-lego.scad, lego-sign.scad, lego.scad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]
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2017-10-03 Overhaul of powershell scripts More parameter passing Generate all sample legos in a script
    [command-line-lego.scad, lego.scad]
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2017-10-03 Added /images directories Added grove module generator WIP Main lego file simplified ring generator
    [lego.scad, lego_grove_customizer.scad, parametric-lego-enclosure.scad]
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2017-10-03 Added stiffeners Closes #1
    [lego.scad]
2017-10-03 Reduced the 4x ring drawing on the bottom, resulting in higher speed Partially Fixes #2
    [lego.scad]
2017-10-03 Re-generated STLs Minor fixes
    [lego.scad]
2017-10-04 Sign generate updated with latest LEGO models and improvements Lower sign text line in extruded text fixed
    [lego-sign-thingiverse.scad, lego-sign.scad]
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2017-10-21 Vertical stiffener bars at the outside shell contact point
    [lego.scad, lego_parameters.scad]
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2017-10-25 Corrected 1z1 socket ring error
    [lego.scad, lego_parameters.scad]
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2017-11-06 Corner bolt holes fixed up Corner bolt holes now M3 compatible
    [lego.scad, lego_parameters.scad, technics.scad]
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2017-11-07 Fixed some multi-layer h and bolt_hole paramaters-not-passed errors Starting to update calibration-blocks with recent changes
    [lego-calibration.scad, lego-parameters.scad, lego-technic.scad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]
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2017-11-09 Lego Technics inclue file fixed
    [lego-calibration.scad, lego-parameters.scad, lego-technic.scad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]
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2017-11-22 Multi-story lego top vents fixed
    [lego-parameters.scad, lego-technic.scad]
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2017-11-27 Inverted print rim on motor customizer NGEN calibration
    [lego-calibration.scad, lego-parameters.scad, lego-technic.scad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]
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2017-12-01 Fixed end sheaths for w=1 Removed unused knob_cuts features
    [lego-parameters.scad, lego-sign.scad, lego-technic.scad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]
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2017-12-08 Vive mount updates with pin holders Slightly looser socket grid defaults
    [lego-parameters.scad, lego-vive-tracker-mount.scad, technic-pin.scad]
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2017-12-13 Updated model for compute stick, not compatible with newer OpenSCAD Vive tracker screw and model updates
    [lego-calibration.scad, lego-endcap-enclosure.scad, lego-endcap-intel-compute-stick-enclosure.scad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]
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2017-12-19 Powershell script updates Removed print calibration settings to a separate file Removed "tweak" paramaters as potentially confusing / text noise
    [lego-double_sided-knob-panel.scad, lego-gunrail-mount.scad, lego-knob-panel.scad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]
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2018-01-08 Motor model update Flex test print
    [lego-motor.scad]
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2018-01-11 Flex knobs are much taller
    [lego-sign.scad, print-parameters.scad]
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2018-01-15 Fix calibration parameter passing; wider side shell for flex materials; regen for flexible materials
    [lego-calibration.scad, lego-parameters.scad, print-parameters.scad]
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2018-01-16 Improved defeather and bottom stiffener slot width for large nozzle support
    [lego-parameters.scad, lego.scad, print-parameters.scad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]
2018-01-16 Bottom stiffener offset correction
    [lego.scad]
2018-01-16 Restore mid-stiffener in multi-layer blocks
    [lego-parameters.scad, lego.scad, print-parameters.scad]
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2018-01-22 Fixed a few issues like sign bottom. Regenerated models
    [PELA-block.scad, PELA-double-sided-knob-panel.scad, PELA-endcap-enclosure.scad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]
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2018-01-22 Minor print-param change for NGEN, less tight
    [PELA-print-parameters.scad]
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2018-02-03 Motor enclosure fixes; endcap enclosure row 0 supports rotated
    [PELA-endcap-enclosure.scad, PELA-motor-enclosure.scad, PELA-parameters.scad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]
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2018-02-26 PNG no longer git LFS else images break; make file STL param
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2018-02-27 knob panel revert
    [PELA-knob-panel.scad]
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2018-03-06 NGEN parameter tuning, looser bottom
    [PELA-box-enclosure.scad, PELA-knob-panel.scad, PELA-print-parameters.scad]
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2018-03-08 Website error check; README and SLICER text updated
    [PELA-block.scad, PELA-box-enclosure.scad, PELA-calibration-set.scad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]
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2018-03-14 Removing Anker enclosure (too big and slow)
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2018-03-26 Remove pre-render- causing errors in complex models downstream
    [PELA-technic-block.scad]
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2018-04-16 Switch to PLA; NGEN looser bottom fit
    [PELA-endcap-enclosure.scad, PELA-endcap-intel-compute-stick-enclosure.scad, PELA-print-parameters.scad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]
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2018-05-18 NGEN settings; fix panel height for socket panel
    [PELA-print-parameters.scad, PELA-socket-panel.scad]
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2018-06-14 PQ12 motor shifted to sideways orientation (solves thin sidewall problem)
    [PELA-actuonix-pq12-linear-actuator-endcap-enclosure.scad]
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2018-09-03 Drop bottom type zero negative space fix
    [PELA-box-enclosure.scad]
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2018-09-09 Box enclosure better missing wall logic
    [PELA-box-enclosure.scad]
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2018-09-10 Pi board mount name fix
    [PELA-raspberry-pi3-board-mount.scad, PELA-technic-block.scad]
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2018-09-11 Updates to match drift car- new Servo board container, fixes to Pi container
    [PELA-board-mount.scad, PELA-box-enclosure.scad, PELA-pca9685-servo-board-mount.scad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]
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2018-09-13 Update throughholes fix; add openbeam15; spelling fixes to README
    [PELA-openbeam15-twist-connector.scad, PELA-print-parameters.scad, PELA-technic-block.scad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]
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2018-09-13 Update twist connector to fix display and make into a PELA panel; Pin array display fix
    [PELA-openbeam15-twist-connector.scad, PELA-print-parameters.scad, PELA-technic-pin-array.scad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]
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2018-09-17 Update socket flexture- better official lego short knob hold
    [PELA-block.scad, PELA-print-parameters.scad, PELA-socket-panel.scad]
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2018-09-18 Fix to boardmount models
    [PELA-board-mount.scad]
2018-09-18 Board holder Pi3 fixes
    [PELA-block.scad, PELA-print-parameters.scad, PELA-raspberry-pi3-board-mount.scad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]
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2018-09-18 Box eonclusure bottom fix
    [PELA-box-enclosure.scad]
2018-09-18 Remove (slow) intel-compute-stick enclosure (it will be replaced soon)
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2018-09-25 Slot mount fixed
    [PELA-slot-mount.scad]
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2018-09-26 Fix box enclosure
    [PELA-box-enclosure.scad]
2018-09-26 Board mount, partial fix
    [PELA-pi3-box-enclosure.scad, PELA-raspberry-pi3-board-mount.scad, PELA-sparkfun-pro-micro-box-enclosure.scad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]
2018-09-28 Pin minimum base size; several other small fixes
    [PELA-knob-panel.scad, PELA-panel-sign.scad, PELA-socket-panel.scad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]
2018-09-28 Fixes to box enclosure l and w propigation into walls()
    [PELA-box-enclosure.scad, PELA-raspberry-pi3-box-enclosure.scad, PELA-sparkfun-pro-micro-box-enclosure.scad]
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2018-10-01 Fix calibration blocks side holes
    [PELA-calibration-set.scad, PELA-calibration.scad]
2018-10-01 Fixes to compute stick airholes
    [PELA-box-enclosure.scad, PELA-intel-compute-stick-box-enclosure.scad]
2018-10-01 Compute stick end hole fix
    [PELA-intel-compute-stick-box-enclosure.scad]
2018-10-02 Calibration set top fix; added intel compute stick lid
    [PELA-calibration-set.scad, PELA-calibration.scad, PELA-intel-compute-stick-box-enclosure.scad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]
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2018-10-05 Mount fix; change to TPU95
    [PELA-print-parameters.scad, PELA-slot-mount-30degree.scad, PELA-technic-block.scad]
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2018-10-09 Socket panel fix
    [PELA-intel-compute-stick-box-enclosure.scad, PELA-knob-panel.scad, PELA-parameters.scad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]
2018-10-09 Shorter knob height, thinner top deck for panels (and elsewhere)
    [PELA-parameters.scad]
2018-10-10 Updates slot mount; panel without sockets fixes
    [PELA-block.scad, PELA-double-sided-knob-panel.scad, PELA-knob-panel.scad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]
2018-10-10 Updates to velcro mount; fixes to grove module holder
    [PELA-grove-module-enclosure.scad, PELA-intel-compute-stick-endcap-enclosure.scad, PELA-velcro-mount.scad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]
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2018-10-14 Fixed names on technic components
    [PELA-technic-bar-30degree.scad, PELA-technic-bar-45degree.scad, PELA-technic-bar.scad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]
2018-10-24 Sign length fix; bar deskin to allow 30 and 45 to build without gaps; board mount partial fix
    [PELA-board-mount.scad, PELA-box-enclosure.scad, PELA-pca9685-servo-board-mount.scad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]
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2018-10-25 Bottom mount corrections to board holder
    [PELA-board-mount.scad, PELA-box-enclosure.scad, PELA-pca9685-servo-board-mount.scad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]
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2018-10-26 Fixed https links; top vents fixed; pi mount bottom corrugation; removed rail and rib mounts
    [PELA-block.scad, PELA-box-enclosure.scad, PELA-calibration-set.scad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]
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2018-10-29 ESP tighter fit
    [PELA-esp32-board-mount.scad]
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2018-10-31 Updates to handle block_height parameter also for panel_height calculations; addressing missing space in box-enclosure
    [PELA-box-enclosure.scad, PELA-double-sided-knob-panel.scad, PELA-grove-module-enclosure.scad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]
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2018-12-04 Fix hole override on technic bars
    [PELA-pi3b-technic-mount.scad, PELA-technic-bar.scad]
2018-12-07 Updated Pi make to fix typos
    [PELA-technic-pi-camera-mount.scad, PELA-technic-pi3b-mount.scad]
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2018-12-09 Fixed typos and bottom of Pi3 board mount is now open (simpler print)
    [PELA-raspberry-pi3-board-mount.scad, PELA-technic-respeaker-core-v2-clear-ring.scad, PELA-technic-respeaker-core-v2-mount.scad]
2018-12-11 Monocrhome top test; center ring positioning fix; don't batch make non-displayed support example
    [PELA-technic-respeaker-core-v2-mount.scad, PELA-technic-respeaker-core-v2-top.scad]
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2018-12-20 Renaming simplified paths for shorter names
    [PELA-arduino-mega-board-mount.scad, PELA-board-mount.scad, PELA-nodemcu-32s-board-mount.scad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]
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2018-12-20 Flex material
    [print-parameters.scad]
2018-12-22 Renaming to fix broken links
    [PELA-technic-nodemcu-v2-knob-mount.scad, PELA-technic-raspberry-pi-camera-mount.scad, PELA-technic-raspberry-pi3b-corner.scad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]
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2019-01-06 Ability to disable auto center sockets when walls are too thin
    [PELA-socket-panel.scad, block.scad, parameters.scad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]
2019-01-06 Axle holes between socket holes in bottom when extruder is large no longer have a socket-grab ridghe
    [block.scad]
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2019-01-21 Remove extra 90 and 120 degree bend pieces; tune TPU95 sockets to be less tight
    [PELA-technic-bar-120degree.scad, PELA-technic-bar-90degree.scad, print-parameters.scad]
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2019-01-22 Fix - to _ typo in function name
    [PELA-pir-technic-mount.scad, PELA-raspberry-pi3-technic-camera-mount.scad, PELA-raspberry-pi3-technic-cover.scad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]
2019-01-23 Fixes to twist bar use in rectangular structures like board_mount and technic_cover
    [PELA-raspberry-pi3-technic-cover.scad, PELA-technic-bar.scad, PELA-technic-board-mount.scad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]
2019-01-23 Cover with twist error fixes
    [PELA-raspberry-pi3-technic-cover.scad, PELA-raspberry-pi3-technic-mount.scad, PELA-socket-panel.scad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]
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2019-01-24 Fixed param errors in block.scad
    [block.scad]
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2019-01-25 Fixing twist bar use in various mounts WIP
    [PELA-pir-technic-mount.scad, PELA-raspberry-pi3-camera-technic-mount.scad, PELA-raspberry-pi3-technic-camera-mount.scad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]
2019-01-25 Removing some errors from side_hole variable passing
    [PELA-grove-module-enclosure.scad, PELA-technic-board-mount.scad, technic-block.scad]
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2019-01-28 Fixed some warnings
    [PELA-grove-module-enclosure.scad, PELA-raspberry-pi3-camera-technic-mount.scad, PELA-stmf4discovery-box-enclosure.scad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]
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2019-01-29 Fix pir make
    [parameters.scad, style.scad]
2019-01-29 Fixing many parameters for customizer; move watcher rust code in
    [PELA-arduino-mega-knob-mount.scad, PELA-block.scad, PELA-box-enclosure.scad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]
2019-01-29 Fixed board mount twist calculations
    [PELA-raspberry-pi3-camera-technic-mount.scad, PELA-raspberry-pi3-technic-cover.scad, PELA-raspberry-pi3-technic-mount.scad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]
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2019-01-30 Panel fixup
    [PELA-arduino-mega-knob-mount.scad, PELA-block.scad, PELA-box-enclosure.scad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]
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2019-01-30 Fixes to build warnings
    [PELA-camera-mount-screw.scad, PELA-pir-technic-mount.scad, PELA-raspberry-pi3-camera-mount.scad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]
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2019-01-31 axle and cross axle customizer fixup
    [PELA-technic-axle.scad, PELA-technic-cross-axle.scad]
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2019-02-01 Updated models while fixing axle-hole-too-small WIP
    [PELA-block.scad, PELA-technic-block.scad, PELA-vive-tracker-mount.scad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]
2019-02-01 Axle hole radius fix
    [PELA-technic-block.scad, style.scad]
2019-02-01 Side hole tweak fixed
    [print-parameters.scad]
2019-02-01 bottom tweak fixed
    [PELA-block.scad, PELA-technic-block.scad]
2019-02-03 Knob panel fix assertion
    [PELA-block.scad, PELA-camera-mount-screw.scad, PELA-grove-module-enclosure.scad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]
2019-02-04 Fix various model warnings and errors; tighten board mount padding
    [PELA-box-enclosure.scad, PELA-intel-compute-stick-box-enclosure.scad, PELA-knob-mount.scad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]
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2019-02-05 Fixing parameters with cut
    [PELA-arduino-mega-knob-mount.scad, PELA-block.scad, PELA-box-enclosure.scad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]
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2019-02-06 style default solid upper layers; socket ring size function fixup
    [PELA-block.scad, PELA-technic-block.scad, material.scad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]
2019-02-06 Calibration bar correction to sockets and knobs
    [PELA-block.scad, PELA-calibration.scad, PELA-technic-bar.scad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]
2019-02-06 Calibration bar fixed; calibration documentation in material.scad
    [PELA-arduino-mega-knob-mount.scad, PELA-block.scad, PELA-box-enclosure.scad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]
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2019-02-07 Fix calibration block bottom socket inner second cut
    [PELA-technic-block.scad]
2019-02-07 Sheath length fixed
    [PELA-box-enclosure.scad, PELA-n20-gearmotor-enclosure.scad, PELA-panel-sign.scad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]
2019-02-07 Side hole length fix
    [PELA-technic-block.scad]
2019-02-08 Add parameterized sliders to customizer; fix width shield bug
    [PELA-arduino-mega-knob-mount.scad, PELA-block.scad, PELA-box-enclosure.scad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]
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2019-02-11 Fixed cutspace on strap mount
    [PELA-strap-mount.scad]
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2019-02-14 Fix servo board links
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2019-02-14 Technic mount fixes to cutout centering logic
    [PELA-pir-technic-mount.scad, PELA-raspberry-pi3-camera-technic-mount.scad, PELA-raspberry-pi3-technic-mount.scad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]
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2019-02-14 Update README.md
    Technic mount link fix
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2019-02-15 Fixing up Pi3 case
    [PELA-raspberry-pi3-technic-mount.scad, PELA-technic-board-mount.scad]
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2019-02-26 Edits to fix minor issues in vive mount and undef parameter passing to technic-block from box mounts
    [PELA-arduino-mega-knob-mount.scad, PELA-intel-compute-stick-box-enclosure.scad, PELA-knob-mount.scad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]
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2019-02-28 Text on box fix
    [PELA-raspberry-pi3-technic-mount.scad, PELA-technic-box.scad, PELA-technic-mount.scad]
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2019-03-01 Knob enclosure fixup
    [PELA-knob-mount.scad, PELA-nodemcu-32s-knob-mount.scad, PELA-pca9685-servo-knob-mount.scad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]
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2019-03-06 Box enclosure fix
    [PELA-box-enclosure.scad, PELA-technic-mount.scad]
2019-03-06 Node v2 fix
    [PELA-nodemcu-v2-technic-mount.scad]
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2019-03-18 Technic mount fix
    [PELA-respeaker-mic-array-v2-technic-mount.scad, PELA-technic-mount.scad]
2019-03-18 Remove clean; fix parameters passed to technic mount
    [PELA-calibration.scad, PELA-nodemcu-v2-technic-mount.scad, PELA-pir-technic-mount.scad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]
2019-03-18 Knob mount fix parameters
    [PELA-arduino-mega-knob-mount.scad, PELA-box-enclosure.scad, PELA-knob-mount.scad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]
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2019-03-20 Change respeaker v2 cover design to avoid bumping into the mics
    [PELA-respeaker-mic-array-v2-technic-mount.scad]
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2019-03-20 Fix block_height param in skin()
    [PELA-block.scad]
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2019-03-21 Bigger clearance on respeaker v2
    [PELA-respeaker-mic-array-v2-technic-mount.scad]
2019-03-21 pi3 case fixup
    [PELA-raspberry-pi3-technic-mount.scad, PELA-technic-mount.scad]
2019-03-22 Relaxed twist assertion- allow more flex but less clear twistbar enclosures
    [PELA-technic-mount.scad]
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2019-04-01 Minor fixes
    [PELA-block.scad, PELA-technic-mount.scad]
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2019-04-09 Pi camera fix; discovery board link fix
    [PELA-panel-sign.scad, PELA-raspberry-pi3-camera-technic-mount.scad, PELA-stmf4-discovery-technic-mount.scad]
2019-04-09 Panel sign- fix for use as a library
    [PELA-panel-sign.scad]
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2019-04-11 Continued _ fixup to parameters passed
    [PELA-block.scad, PELA-calibration.scad, PELA-knob-panel.scad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]
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2019-04-21 More corner fixup to bent-beam
    [PELA-technic-beam.scad, PELA-technic-bent-beam.scad, PELA-technic-twist-beam.scad]
2019-04-21 Bent beams fixup done
    [PELA-respeaker-core-v2-mount.scad, PELA-technic-angle-connector.scad, PELA-technic-beam.scad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]
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2019-04-22 Updated many assert() on inputs; panel fixup; box enclosure fixup
    [PELA-block.scad, PELA-box-enclosure.scad, PELA-knob-panel.scad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]
2019-04-22 Fixes to grove
    [PELA-grove-module-enclosure.scad, PELA-intel-compute-stick-box-enclosure.scad]
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2019-05-07 Fix link to 9685 technic mount
2019-05-08 Technic box bottom text fix
    [PELA-technic-box.scad]
2019-05-09 Pi fix to layer height; realsense update
    [PELA-raspberry-pi3-technic-mount.scad, PELA-t265-realsense-tracking-camera-technic-mount.scad]
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2019-05-14 Refactor to fix some _ in params; calibration WIP cleanup
    [PELA-arduino-mega-knob-mount.scad, PELA-arduino-uno-technic-mount.scad, PELA-block.scad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]
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2019-05-15 Fixup to pin array _
    [PELA-technic-pin-array.scad, PELA-technic-pin.scad]
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2019-05-16 Fix pi zero w cover cutouts
    [PELA-raspberry-pi-zero-w-technic-mount.scad, PELA-technic-axle.scad, threads.scad]
2019-05-16 Technic hole strap mount; fix full width holes to have lock rings all along
    [PELA-strap-mount.scad, PELA-technic-block.scad]
2019-05-16 technic box top text fixed
    [PELA-technic-box.scad, PELA-technic-mount.scad, PELA-technic-twist-beam.scad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]
2019-05-17 Axle merge fix; rendered hub
    [PELA-technic-axle.scad]
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2019-05-17 TPU85 calibration; bent beam Render section
    [PELA-technic-bent-beam.scad, material.scad]
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2019-05-19 Rount motor enclosure replaces servo enclosure
    [PELA-servo-motor-enclosure.scad]
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2019-05-22 Slightly tighter length to 9685 case
    [PELA-pca9685-servo-board-technic-mount.scad]
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2019-05-24 Fixup after rebuild- technic sign; remove deprecated servomotor design
    [PELA-technic-sign.scad]
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2019-05-24 Technic box various center type fixes
    [PELA-box-enclosure.scad, PELA-calibration.scad, PELA-esc-mount.scad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]
2019-05-25 Technic mount updated; t box fixes
    [PELA-technic-box.scad, PELA-technic-mount.scad]
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2019-05-25 Fixing parameter passing using pi zero w as example
    [PELA-block.scad, PELA-camera-mount-screw.scad, PELA-esc-mount.scad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]
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2019-05-26 Fixing skin application to basic block features (for negative skin)
    [PELA-block.scad, PELA-socket-panel.scad]
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2019-05-27 Jetson nano fixup
    [PELA-jetson-nano-technic-mount.scad, PELA-nodemcu-v2-technic-mount.scad, PELA-pca9685-servo-board-technic-mount.scad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]
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2019-05-30 Discovery fixup
    [PELA-stmf4-discovery-technic-mount.scad, PELA-t265-realsense-tracking-camera-technic-mount.scad]
2019-05-30 Uno nano and PIR fixup
    [PELA-arduino-uno-technic-mount.scad, PELA-jetson-nano-technic-mount.scad, PELA-pir-technic-mount.scad]
2019-05-30 Pi3 powerbank and uno fixup
    [PELA-arduino-uno-technic-mount.scad, PELA-intel-compute-stick-box-enclosure.scad, PELA-powerbank-technic-mount.scad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]
2019-05-30 Pi camera fixup
    [PELA-raspberry-pi-camera-technic-mount.scad]
2019-05-30 Pi zero w fixup
    [PELA-raspberry-pi-camera-technic-mount.scad, PELA-raspberry-pi-zero-w-technic-mount.scad]
2019-05-30 Node MCU and 9685 fixs; partial respeaker core v2 fix
    [PELA-nodemcu-v2-technic-mount.scad, PELA-pca9685-servo-board-technic-mount.scad, PELA-respeaker-core-v2-mount.scad]
2019-05-31 Shorter front to t265 case to avoid seeing it in ultra-wide-angle cameras
    [PELA-pca9685-servo-board-technic-mount.scad, PELA-t265-realsense-tracking-camera-technic-mount.scad]
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2019-06-04 Fixing vertical sign
    [PELA-panel-sign.scad, PELA-technic-block.scad, PELA-vertical-sign.scad]
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2019-06-05 Technic sign and bent beam
    [PELA-technic-bent-beam.scad, PELA-technic-sign.scad]
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2019-06-10 Fix pin, vive screw and mount
    [PELA-camera-mount-screw.scad, PELA-technic-pin-array.scad, PELA-technic-pin.scad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]
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2019-06-17 Pi3 case gen fix
    [PELA-raspberry-pi3-technic-mount.scad, material.scad]
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2019-06-19 Retaining wall in t265; fixed bad references after box-enclosure was moved
    [PELA-arduino-uno-technic-mount.scad, PELA-raspberry-pi-zero-w-technic-mount.scad, PELA-t265-realsense-tracking-camera-technic-mount.scad]
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2019-06-20 Add technnic rail rendering; T265 camera tighter fit
    [PELA-t265-realsense-tracking-camera-technic-mount.scad]
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2019-06-25 Fixed Respeaker core v2
    [PELA-respeaker-mic-array-v2-technic-mount.scad]
2019-06-27 Less tight Nano fit; fix box enclosure back cutout Y
    [PELA-box-enclosure.scad, PELA-jetson-nano-technic-mount.scad]
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2019-07-17 Correct naming type on simplified peg
    [PELA-simplified-technic-peg.scad]
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2019-07-22 Flex pin; respeaker core v2 cutout fix
    [PELA-respeaker-mic-array-v2-technic-mount.scad, PELA-simplified-technic-peg-flexmaterial.scad, material.scad]
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2019-08-07 Simplified peg- less tight fit in axle hole
    [PELA-simplified-technic-peg.scad]
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2019-08-19 Nano tuning of cover for new shorter base
    [PELA-jetson-nano-technic-mount.scad]
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2019-08-20 Taller nano battle cap; more space for front connectors on shortened nano case
    [PELA-jetson-nano-battle-cap.scad, PELA-jetson-nano-technic-mount.scad]
2019-09-10 Nano more board space; antenna mounts raised to avoid headers
    [PELA-jetson-nano-technic-mount.scad]
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2019-11-25 Fixed link to rail in README; simplified initial display state of beam elements
    [PELA-technic-angle-connector.scad, PELA-technic-bent-beam.scad, PELA-technic-corner.scad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]
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2019-12-17 Battle cap typo fix; additonal variant with PC
    [PELA-jetson-nano-battle-cap.scad]
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2019-12-30 Remove ]] to fix various customizer; Toshiba HDD tuneup
    [PELA-arduino-uno-technic-mount.scad, PELA-jetson-nano-battle-cap.scad, PELA-jetson-nano-technic-mount.scad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]
2020-01-02 Fix size of Toshiba drive case
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

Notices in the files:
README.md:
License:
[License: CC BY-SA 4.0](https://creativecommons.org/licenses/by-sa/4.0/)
